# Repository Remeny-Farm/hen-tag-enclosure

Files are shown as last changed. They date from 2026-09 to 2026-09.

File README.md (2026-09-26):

> **Moved (2026-09-26).** This repository is archived. The enclosure now lives, with its full history, in the Open Source Farming catalogue:
> https://github.com/Remeny-Farm/open-source-farming-catalog/tree/main/projects/holyiot-25008-enclosure
> Contributions, issues and build reports go there. The site entry is https://opensource.mootopia.wtf/#holyiot-25008-enclosure (English) and https://opensource.remeny.farm/#holyiot-25008-enclosure (Hungarian).

# Hen Tag Enclosure

Parametric, 3D-printed enclosure for the Remeny Farm hen tag: a small
BLE activity tag worn by free-range laying hens under the farm's hen-patron
program. This repository holds the mechanical design only — the parametric
[build123d](https://build123d.readthedocs.io/) CAD source, the verification
and per-tag cap generators, and the physical evidence gathered from printing
and fitting it — as real solid-body CAD (STEP as well as STL), not a dead
triangle mesh.

## Hardware context

The tag is built around a **Holyiot 25008** module (Nordic **nRF54L15** SoC,
ST **LIS2DH12** accelerometer) powered by a **CR2032** coin cell. It is worn
by the hen on a figure-eight elastic harness through the enclosure's in-plane
side tabs, assembled and installed by farm staff following the documented
procedure. The electronics and firmware live in a separate, private
repository; this repository covers the mechanical enclosure only.

The design is welfare-first: the current (Revision B) model lands at
**10.92 g assembled**, conductive/carbon-fibre filament is strictly
prohibited (it detunes the 2.4 GHz antenna and creates an ESD/short hazard
against the exposed coin-cell terminals), and every geometry decision is
checked against interference, wall thickness and printability before it is
considered done. See [`docs/requirements.md`](docs/requirements.md) for the
full material and welfare-adjacent requirements this design has to satisfy.

## Goals

- **Durable, hen-safe enclosure** — a sealed transparent PETG housing (radial
  O-ring, target IP54-level dust/splash protection — not yet tested), no
  conductive filament, and a mass budget held close to a 10 g target.
- **Per-hen customizable cap** — [`cad/cap_marking.py`](cad/cap_marking.py)
  generates a deterministic, per-hen cap (id number, an optional short
  message, an icon) and exports it straight to a ready-to-slice, multi-colour
  Bambu Studio project.
- **Accessory platform** — [`platform/`](platform/) proposes a keeper collar
  and bayonet mount so decorative and functional accessories can be added
  without ever modifying or replacing the shipping cap. Proposal stage, open
  for contribution.
- **Community contributions** — parametric, machine-verified, test-covered
  source with dated physical lab notes and explicit verified-vs-unverified
  labeling, so outside contributors have a real basis to trust and extend the
  design. See [`CONTRIBUTING.md`](CONTRIBUTING.md).

## Per-hen cap customisation

Patrons choose a colour scheme, an icon or a centre pattern and a top-band
pattern for their hen's cap in the app and lock the design; staff batch one
scheme's locked caps onto one printer plate. Design and requirements:
[`docs/superpowers/specs/2026-09-14-hen-cap-customisation-design.md`](docs/superpowers/specs/2026-09-14-hen-cap-customisation-design.md).

```sh
cd cad
uv run --python 3.12 cap_marking.py 67 --icon sun --band dots     # one cap with a band pattern
uv run --python 3.12 cap_batch.py fixtures/batch_sample.json       # batch JSON -> plate + manifest + proofs
cd ../editor && pnpm install && pnpm dev                            # the patron editor prototype
```

- [`cad/catalog.json`](cad/catalog.json) is the source of truth for the
  colour schemes (base + two free colours, Prusament Clear window; five on
  offer since 2026-09-18, three retired ones kept printable for designs
  already locked on them), the packs (basic free, vibe 50, drop 300–1000
  limited, priced per item), 34 icons, 16 patterns, the five colour zones
  (a translucent filament may not go on the opaque ring or number) and the
  fees; the app ships an identical copy.
  [`cad/cap_motifs.py`](cad/cap_motifs.py) holds every motif as parametric
  geometry, [`cad/check_motifs.py`](cad/check_motifs.py) proves them printable.
- [`cad/cap_batch.py`](cad/cap_batch.py) turns the admin's batch JSON into
  `plate_<batch>_P1S.3mf` (6 × 6, up to 36 caps, AMS 1 clear / 2 text /
  3 accent, print settings baked in), a manifest and a proof SVG per cap.
  A 36-cap plate slices to 36 objects in an estimated 4 h 13 m
  ([lab note](docs/lab/2026-09-14-cap-batch-plate.md)); **no plate has been
  printed yet.**
- [`editor/`](editor/) is the drop-in patron editor built with chirp's own
  UI package; see its README for how it maps into the chirp repository.

## Repository structure

| Path | Contents |
|---|---|
| [`DESIGN.md`](DESIGN.md) | Full mechanical design spec: decisions, verification results, print settings, open questions. |
| [`docs/requirements.md`](docs/requirements.md) | Source-of-truth requirements: materials, sealing/ingress target, conformal-coating protocol, form factor. |
| [`docs/lab/`](docs/lab/) | Dated lab notes: physical measurements, print trials, photo-based findings. |
| [`cad/`](cad/) | Parametric build123d source, the per-tag cap generator, the batch CLI and plate writer, the verification scripts, and the test suites. |
| [`editor/`](editor/) | Patron cap-editor prototype (React, chirp UI package), browser-testable, drop-in for chirp. |
| [`cad/out/`](cad/out/) | Exported STL/STEP. Stable printables (body, cap, fit coupons) are committed; per-tag and debugging outputs are gitignored — see `cad/out/.gitignore`. |
| [`platform/`](platform/) | Accessory-platform **proposal**: keeper collar, bayonet interface spec, saddle integration. Not yet built. |
| [`CONTRIBUTING.md`](CONTRIBUTING.md) | How to contribute: environment, verification requirements, lab-note style, accessory safety envelope. |
| [`LICENSE`](LICENSE) | MIT license. |

## Quickstart

Both CAD scripts carry [PEP 723](https://peps.python.org/pep-0723/) inline
dependencies, so `uv` resolves everything (build123d, bd_warehouse) on first
run. No virtualenv, nothing installed into the repository.

```sh
cd cad

# Build the enclosure and export STEP + STL to out/
uv run --python 3.12 hen_tag_enclosure.py

# 39 machine checks (interference, fit, bayonet, wall thickness, seal, harness) + half sections
uv run --python 3.12 verify.py

# Generate one hen's cap: id, optional message, icon
uv run --python 3.12 cap_marking.py 67 --top "Bözsi!" --icon heart

# Generator test suite (add --bambu for the full Bambu Studio export path)
uv run --python 3.12 test_cap_marking.py

# Real-slicer check: warnings + travels over open air (needs Bambu Studio)
uv run --python 3.12 slice_check.py

# Bambu Studio project with all four parts and the print settings baked in
uv run --python 3.12 slice_check.py --project   # -> out/hen_tag_revC_P1S.3mf
```

First run downloads the OCCT wheel (~60 MB) and a CPython 3.12 toolchain;
after that it is cached. `verify.py` exits non-zero on any failed check, so
it works as a pre-commit or CI gate. See [`cad/README.md`](cad/README.md)
for the full command reference, including re-checking a part against the
real slicer.

## Print settings

| Setting | Value | Why |
|---|---|---|
| Material | Transparent PETG | Impact resistance, UV stability, low moisture absorption; keeps the LED and lettering readable. |
| Nozzle | 0.40 mm | Thinnest wall in the design is 0.80 mm = 2 perimeters. |
| Layer height | 0.16 mm | The bayonet ramps and the O-ring groove need the resolution. |
| Perimeters | 3 | The bayonet lips make the skirt 5 lines thick in places. |
| Wall generator | **Arachne** | Variable-width walls absorb the lips as walls, not infill islands. |
| Avoid crossing walls | **On** | Routes travels over the print, not across the open bore; without it PETG strings the bore (58 → 3 crossing travels on the cap coupon). |
| Infill | 30 %+ | Parts are nearly all perimeter anyway. |
| Supports | None | Verified by slicing — all four parts return `Success.` with zero warnings. |
| Orientation | Already baked into the exported STLs | Drop them on the plate as-is; re-orienting the cap turns its top plate into a ~28 mm bridge. |

Or skip the settings altogether: [`cad/out/hen_tag_revC_P1S.3mf`](cad/out/hen_tag_revC_P1S.3mf)
is a Bambu Studio project with the four printables on one P1S plate and every
setting above already applied — open, slice, print.

Full rationale, tolerances and the slicer verification log are in
[`DESIGN.md`](DESIGN.md#print-settings).

## Design highlights

- **Radial seal, not an axial face seal** — the O-ring seals on a bore
  diameter instead of a compressed flange, which also removes ~1.7 g of pure
  overhead. [`DESIGN.md`](DESIGN.md#1-radial-seal-not-the-axial-face-seal)
- **Bayonet closure below the seal** — three lugs and self-locking helical
  ramps replace a thread whose ridges were thinner than one extrusion; every
  face on both parts prints without support, and the O-ring never crosses the
  lugs. [`DESIGN.md`](DESIGN.md#9-bayonet-not-a-thread)
- **Three-colour coin cap** — a deterministic per-hen cap with coin-style
  bent lettering, an accent-ring icon, and a clear shell so the LED needs no
  aligned window. [`DESIGN.md`](DESIGN.md#8-customer-cap-clear-shell-big-coin-lettering-accent-core)
- **Flat underside** — verified at 0.000 mm³ of material below the floor
  plane, so nothing presses on the hen but the harness itself.
  [`DESIGN.md`](DESIGN.md#7-in-plane-side-tabs-for-the-harness)
- **In-plane side tabs** — the harness elastic wraps a bar on two flat tabs
  in the plane of the base, which is what makes the flat underside possible.
  [`DESIGN.md`](DESIGN.md#7-in-plane-side-tabs-for-the-harness)

## Status

**v1 is Revision C geometry.** It is machine-verified — 39 checks in
`cad/verify.py`, all passing — but that is a claim about the model, not about
a worn device:

- **Revision A** was printed and fitted on a Bambu Lab P1S: dimensions good,
  and its thread mated on that one pair. Later caps tore along the thread,
  whose ridges compute to less than one extrusion wide, so revision C
  replaced it with a bayonet.
- **Revision B's body** has also been printed and accepted the board in its
  intended orientation, and revision B sliced clean in Bambu Studio.
- **Revision C's bayonet** slices clean and its coupon pair has been printed
  once: dimensions good, lock-up angle not yet reported. The full cap, the
  complete sealed assembly and the harness tabs under load remain untested —
  no O-ring has been compressed, no water has touched it, and no elastic has
  loaded a tab.
- **No hen has worn this device.**

See [`DESIGN.md`](DESIGN.md#verified-evidence-vs-working-hypotheses) for the
full verified-vs-unverified breakdown and the open questions blocking the
next print.

## Animal welfare

The tag is worn continuously by a live animal, so mass and fit are treated as
hard constraints, not just engineering targets. At ~10.9 g assembled the
device is a small fraction of a laying hen's typical body mass — well inside
commonly cited bio-logging guidance of keeping an attached device under
roughly 3 % of body mass — though `DESIGN.md` is explicit that whether the
project's own 10 g figure is a hard welfare limit or a design aspiration is
still an open decision, not yet resolved. The design avoids magnets, sharp
edges and anything a beak could catch or detach; production tags are
assembled and fitted by farm staff, with daily visual checks as part of
normal husbandry. This is not a consumer product for end users to assemble
or fit themselves.

## Accessory platform

[`platform/`](platform/) is a **design proposal**, not a shipping feature:
nothing in it has been printed or tested, and the current shipping design
(`DESIGN.md`, `cad/hen_tag_enclosure.py`) is untouched by it. It describes a
keeper collar and quarter-turn bayonet mount for a family of accessories —
decorative rings, villa-only builds, a mesh saddle — without ever modifying
the personalised cap. It is open for contribution; see
[`platform/README.md`](platform/README.md) for the architecture and
[`platform/accessories.md`](platform/accessories.md) for the hard safety
envelope every accessory design must satisfy.

## Contributing

See [`CONTRIBUTING.md`](CONTRIBUTING.md) for the development environment,
what has to pass before a PR (generators, `verify.py`, the test suite), how
physical evidence is recorded, and the accessory safety envelope.

## License

MIT. See [`LICENSE`](LICENSE).

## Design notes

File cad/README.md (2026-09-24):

# Enclosure CAD

Parametric source for the hen tag enclosure. Solid B-rep modelling via
[build123d](https://build123d.readthedocs.io/) on the OCCT kernel, so the output
is real CAD geometry with true fillets and helical sweeps, exported as **STEP as well
as STL** — the model stays editable in FreeCAD or any other CAD tool rather than
being a dead triangle mesh.

## Running

Both scripts carry PEP 723 inline dependencies, so `uv` resolves everything on
first run. No virtualenv, and nothing is installed into the repository.

```sh
uv run --python 3.12 hen_tag_enclosure.py   # build + export to out/
uv run --python 3.12 verify.py              # 39 machine checks + half sections (+9 with --board-step)
uv run --python 3.12 slice_check.py         # real-slicer check, needs Bambu Studio
```

First run downloads the OCCT wheel (~60 MB) and a CPython 3.12 toolchain; after
that it is cached. `verify.py` exits non-zero when a check fails, so it works as
a pre-commit or CI gate.

**STLs are exported already lying in their print orientation** — the cap and the
female coupon are flipped top-plate-down on export. Drop them on the plate as
they are; re-orienting the cap makes its top plate a ~28 mm bridge. The STEP
files keep the design coordinate system so the model stays readable in CAD.

`slice_check.py` re-checks printability against the real slicer: it runs the
Bambu Studio CLI on the four printables with the P1S 0.4 mm machine, the
0.16 mm process, PETG Basic, and the three settings `../DESIGN.md` asks for
(3 walls, Arachne, avoid crossing walls), then reads the G-code back and
counts travel moves that fly across open air — the bore of the cap, the cavity
and cell pocket of the body — where PETG leaves a string. It fails on a slicer
warning or when a count exceeds a limit set just above the 2026-09-10 numbers.
`--stock` slices with the untouched Bambu profile for comparison, `--keep`
leaves the G-code in `out/slice/`. Skips with exit 0 when Bambu Studio is not
installed.

## Per-tag cap markings — the deterministic tag generator

```sh
uv run --python 3.12 cap_marking.py 67 --top "Bözsi!" --icon heart
uv run --python 3.12 cap_marking.py 12345 --icon star
uv run --python 3.12 cap_marking.py 133 --icon flower --font tahoma
uv run --python 3.12 test_cap_marking.py            # test suite; --bambu for the full path
```

This is the back end for the customer design UI. The inputs are exactly the
customer-facing choices, everything else is fixed:

| Input | Envelope |
|---|---|
| number | **required**, 1–5 digits, bottom arc, 6.0 pt |
| `--top` message | ALL CAPS coin lettering at 5.2 pt; letters incl. Hungarian (ő/ű), digits, space, `.:!?'"+-`; **guaranteed-safe length: 8 characters** (all-'W' worst case), typical texts fit ~11–13 — over-length is rejected with the measured span |
| `--icon` | `heart` / `star` / `flower` / `none` — parametric shapes in the centre |
| `--font` | curated list: verdana (default), tahoma, arial, futura, din, rounded |

**Layout (second print-driven revision): the whole shell is CLEAR PETG.** The
first trial printed the lettering at a 2.9 mm band and it was unreadable, and
the product look wanted a transparent body anyway. With the shell clear, the
dedicated LED window disappears — the LED shines through wherever it lands, so
there is nothing to align — and the lettering band grows to ~6 mm: double the
letter height, at the price of a shorter message. The centre is a full
**accent disc** (Ø17.2) in the third colour with the icon cut out of it and
inlaid in the text colour — the two colours meet edge to edge, no clear gap.

| Slot | Body | Filament |
|---|---|---|
| 1 | `cap_<n>` | the whole shell — **clear PETG** |
| 2 | `marking_<n>` | lettering + icon, text colour (0.64 mm flush inlay) |
| 3 | `core_<n>` | accent disc, the icon cut from it (0.64 mm flush inlay) |

Deterministic by design: **font sizes are fixed**, misfits are rejected with
measured numbers, and identical input produces **byte-identical** output
(canonically ordered welded meshes, deterministic STL writer, fixed zip
timestamps) — a regenerated tag can be diffed against a shipped one.

Envelope rules the test suite forced: the message is uppercased (a lowercase
descender plus an accented capital outgrows any printable band height, while
accented capitals alone fit), and comma/semicolon/parentheses are excluded
from the charset for the same below-the-baseline reason.

The deliverable for the P1S is **`out/cap_<n>_P1S.3mf`** — a Bambu Studio
project with the three bodies as parts of ONE object (`--assemble` via the
Bambu CLI, so nothing can be arranged apart or dragged out of register) and
the filament slots pre-assigned. Open it, load the project settings, put clear
PETG in AMS slot 1, the text colour in 2, the accent colour in 3, slice. Each
part's `extruder` is patched into `Metadata/model_settings.config`, the
assembler's per-part recentring is undone with measured translations, and the
result is verified numerically against the source solids plus round-tripped
through the CLI. Needs `/Applications/BambuStudio.app`; without it only the
vendor-neutral `cap_<n>.3mf` + per-part STLs are written (assign filaments by
hand in other slicers).

Because the cap prints top-plate-down, all three bodies meet in the first
layers against the plate; the outer face comes out as one smooth plane. There
is no clear layer over or under the inlays — the first layer is already the
final colour. A washed-out colour means the coloured PETG itself is
translucent at 0.64 mm: deepen with `--depth` (up to 0.80) at the cost of
thinner cover above.

The 3MF is written by the script itself: one mesh object per body (libraries
explode the glyphs into a dozen objects), tessellation **welded** (OCCT
duplicates vertices per face; 3MF importers trust the index buffer and the
cracks sliced into "floating region" warnings) and refused if any non-manifold
edge remains. Lettering defaults to **Verdana** with the full Hungarian glyph
set; hairline strokes are lifted by dilation and any printable feature under
0.58 mm is refused. Icons are parametric geometry, no emoji fonts. The cap's
closure, seal and envelope are untouched — `build_cap()` is imported, not
copied.

## Files

| File | Role |
|---|---|
| `hen_tag_enclosure.py` | All geometry. `Params` at the top holds every dimension. |
| `catalog.json` | Schemes, icons, centre/band patterns and fees a patron may choose; the app ships a copy, `test_cap_marking.py` keeps them identical. |
| `cap_design.py` | Catalog loader, `design_hash` (v2, with zone colours), `validate_design` (zone rules incl. no translucent filament on an opaque zone; retired schemes stay valid), `lock_price`; no build123d, shared by the batch CLI and the tests. |
| `cap_motifs.py` | Every icon and pattern as a parametric sketch (34 icons, 3 centre, 13 band patterns; the barcode band is seeded by the serial). |
| `check_motifs.py` | Printability of the whole motif library (erosion/dilation, extents) plus a contact sheet (`--svg`). |
| `cap_svg.py` | Sketch → SVG: `out/layout.json` for the app preview, proof SVGs for the batch. |
| `bambu_project.py` | Pure-Python Bambu Studio plate writer (6 × 6 grid, part extruders, settings template in `bambu/`). |
| `cap_batch.py` | Batch JSON → plate, manifest, proofs; caches bodies per design hash; runs `slice_check.py` on the plate. |
| `test_bambu_project.py`, `test_cap_batch.py` | Writer and batch suites (structure, determinism, refusals, a real slice). |
| `verify.py` | Interference, fit, bayonet, wall thickness, seal and harness checks. |
| `slice_check.py` | Real-slicer check: warnings and open-air travel counts per part; `--project` writes the ready-to-print Bambu project. Needs Bambu Studio. |
| `out/hen_tag_revC_P1S.3mf` | Bambu Studio project: body, cap and both coupons on one P1S plate, print settings baked in. |
| `cap_marking.py` | Deterministic per-tag cap generator (number, message, icon, font). |
| `test_cap_marking.py` | Generator test suite: envelope, rejections, determinism. |
| `out/body.stl` / `.step` | Main housing. |
| `out/cap.stl` / `.step` | Bayonet cap. |
| `out/coupon_*.stl` | Bayonet + groove fit coupons. Print these first: the bayonet has not been printed anywhere yet. |
| `out/section_*.stl` | Half sections, for looking at the internals only. |

## Changing dimensions

Every dimension lives in the `Params` dataclass. Derived values — groove depth,
lug and lip stations, cap diameter, Z stations — are computed properties, so changing
one input propagates correctly instead of leaving stale constants behind.

The values most likely to need correcting, all currently UNVERIFIED:

```python
holder_h   = 4.0    # holder + seated cell, off the PCB face (board itself: STEP)
oring_cs   = 1.50   # measure the ring you actually have
strap_w    = 8.80   # slot length; measure the elastic you actually have
strap_t    = 1.80   # slot width, along the spine
foam_t     = 2.0    # foam ring over a 1.79 mm gap to the board face
```

Board orientation is **holder down, PCB up** — the LED has to look out through
the cap, not at the bird. `cell_fill()` builds the crescent that retains the
holder; `strap_tabs()` builds the in-plane side tabs; `body_lugs()` and
`cap_channels()` build the two halves of the bayonet, both from one helical
sweep helper so their bearing faces share a pitch.

### Batch workflow

1. The app's admin page downloads a `hen-cap-batch/1` JSON: one scheme, up to
   36 locked caps (serial, icon *or* centre pattern, band pattern, design
   hash, hen name). `fixtures/batch_sample.json` is the shape.
2. `uv run --python 3.12 cap_batch.py <batch.json>` refuses the whole batch on
   any problem (schema, `generator_version` ≠ `catalog.json`, unknown ids,
   icon + centre together, a zone colour rule, a translucent filament on the
   ring or number, duplicate serial, bad hash, > 36 caps; a retired scheme is
   accepted) and lists
   every offending cap; otherwise it writes `out/plates/plate_<id>_P1S.3mf`,
   `plate_<id>_manifest.csv` (`position,serial,hen_name,design_hash`,
   positions `1A`…`6F`) and `proof/<design_hash>.svg`, then slices the plate
   through Bambu Studio and reports objects, warnings and the time estimate.
3. Open the plate in Bambu Studio, set AMS 1 = the scheme's base filament,
   2 = Prusament PETG Clear, 3 = colour a, 4 = colour b (`catalog.json` names
   them; the batch CLI prints the mapping), print. The plate carries the
   `Bambu PETG Basic @BBL X1C` preset in all four slots whatever the scheme
   (Prusament, Bambu PETG Basic, or Bambu PETG Translucent in `lavender`'s
   slot 4): the per-filament arrays stay as exported (see
   `bambu_project.py`): temperatures and flow come from that preset, the
   AMS mapping on the printer decides which spool feeds each slot. Whether
   PETG Translucent prints well on the Basic preset is UNVERIFIED.
4. Upload the proofs to the app (file name = design hash).

Patterns must survive a 0.4 mm erosion (feature ≥ 0.8 mm) and a 0.4 mm
dilation without islands merging (gap ≥ 0.8 mm), and every inlay together must
leave ≥ 60 % of the LED ring (r 8.5–11.5) clear; `cap_marking.py` checks all
three. Band patterns live in a fixed window (−10°…190°) that clears a 5-digit
serial by 22°.

After any change, re-run `verify.py` before printing. It is what caught the
assembly-path defect described in `../DESIGN.md`.

## Bayonet fit

Print the coupons and note where the cap stops turning freely. Nominal is 30°
clockwise from the entry slots; anywhere from about 5° to 55° still locks. Then
adjust and regenerate — do not file the parts:

```python
cam_lock   = 30.0   # deg of rotation to nominal contact: raise if it locks early, lower if late
fit_lug_r  = 0.15   # radial clearance, lug crest to channel root: raise if the lugs bind
fit_lug_z  = 0.30   # axial clearance, lug top to channel ceiling
cam_rate   = 0.012  # ramp rise per degree; lower for a longer, softer tightening
```

Note for anyone extending this: the cap is modelled in its **locked** pose, so
the cap solid is already the assembled one. `verify.py` turns it back toward
the entry angle (`pose(phi)`) to prove the drop-on, the free run and the wedge.
Lugs and lips are swept along helices of the same pitch; change `cam_rate` and
both follow.

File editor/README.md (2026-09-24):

# Hen cap editor — prototype

Browser-testable prototype of the patron-facing cap editor from
`../docs/superpowers/specs/2026-09-14-hen-cap-customisation-design.md` §7.
It is written to be dropped into the chirp repository unchanged, so it renders
with chirp's own `@chirpcoop/real-chicken-ui` components and
`@chirpcoop/design-tokens`, aliased **from the chirp checkout's source** — the
chirp repository is read, never written.

```sh
pnpm install
pnpm sync:data     # copies ../cad/catalog.json and ../cad/out/layout.json into src/cap-editor/data/
pnpm dev           # http://localhost:5173 with the in-memory mock client
pnpm test          # vitest + testing-library
pnpm typecheck
pnpm build
```

`CHIRP_DIR` overrides the chirp checkout location (default `../../chirp`);
`tsconfig.json`'s `paths` must be edited to match, tsc cannot read env.

## What it looks like

A three-step game — Palette → Motif → Colours — with the cap on stage and a
summary bar stuck to the bottom. Design decisions, the mobile integration
path and a reviewer checklist: [`DESIGN-NOTES.md`](DESIGN-NOTES.md).

## Rules the code already obeys

- Only `var(--rc-*)` and `@chirpcoop/design-tokens` values in TS/CSS; the
  only colour literals are the filament hexes in `data/catalog.json` (data).
- Deep imports only: `@chirpcoop/real-chicken-ui/components`, `/wallet-pill`,
  `/golden-grain`, `/theme-vars`, `/dialog-focus`, `/armed-confirm`,
  `/styles.css`. Never `/client` or `/index`: they pull `@chirpcoop/client-sdk`
  and recharts in. In chirp these become relative imports inside the package.
- React 19, TypeScript strict, vitest + testing-library, English-only source;
  Hungarian only inside `src/copy/hu.ts`.

## Integration map (landed in chirp on 2026-09-14, PR Remeny-Farm/chirp#2409; kept for orientation)

| Prototype file | Lands in chirp as |
|---|---|
| `src/cap-editor/*.tsx`, `*.css`, `*.test.tsx` | `packages/real-chicken-ui/src/cap-editor/` |
| `src/copy/{hu,en}.ts` | keys in `apps/web/i18n/` catalogs |
| `src/cap-editor/types.ts` (`CapDesignClient`) + `mock-client.ts` | interface stays; SDK adapter in `apps/web/lib/`; mock stays for tests |
| `src/page.tsx` | `apps/web/app/(patron)/my-hen/cap/page.tsx` + client wrapper |
| `src/cap-editor/data/*.json` | data assets under `packages/real-chicken-ui/src/cap-editor/data/` |

## Layout gate (manual, needs Playwright)

`pnpm test` runs in jsdom and cannot see geometry. `pnpm check:layout` drives a
real Chromium against a running dev server and fails on page-level horizontal
overflow on any step at 360 / 390 / 1200 px, on a rail that does not scroll
sideways on its own, on an arrow-focused tile left cut off at the rail edge,
and on any chip / tile / tab / card under 44 px. Playwright is not a
devDependency (browser download), so point `NODE_PATH` at an install that has
it:

```sh
pnpm dev                                          # terminal 1
NODE_PATH=/path/to/node_modules pnpm check:layout  # terminal 2
```

Run it before every UI change lands; the scoring reviewer checks the same
things.

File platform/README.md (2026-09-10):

# Accessory Platform — Design Proposal (separate from the shipping design)

## Purpose & Status

Design for making the existing Rev B tag the mounting platform for a family of
accessories (decorative add-ons, villa builds, saddle integration) **without
changing anything the current tag already does**: LED ring window, coin
lettering, radial seal, bayonet cap, flat underside, harness tabs, mass budget.

- **Status: PROPOSAL. Nothing here has been printed or tested.**
- These files are deliberately separate. `../DESIGN.md` and
  `../cad/hen_tag_enclosure.py` are untouched; the current design remains the
  shipping design and works with or without the platform parts.
- Direction and welfare constraints follow a three-tier model: T1 always-worn
  accessories in the flock, T2 "villa wardrobe" builds only in the wellness
  villa, T3 functional mesh saddle. Active feather pecking exists in the
  flock; summer peaks hit 42 °C.

## Files

| File | Contents |
|---|---|
| [`collar.md`](collar.md) | The keeper collar: the one new load-bearing part. Clamshell ring that locks the cap and carries the bayonet mount. |
| [`accessories.md`](accessories.md) | Bayonet interface spec v0.1, hard safety envelope, T1 catalog (halo ring, flush medallion, low dome), T2 villa rules. |
| [`saddle-integration.md`](saddle-integration.md) | Mesh saddle with grommet window and the fabric-lock ring that registers it to the tag. |

## Architecture in one paragraph

A two-piece **keeper collar** clips around the cap skirt. It is keyed by the two
harness tabs (so it cannot rotate), rests on the tab shoulders, and hooks over
the cap rim with a lip that stops **outside** the lettering band — every printed
feature of the cap face stays visible. Clamping the skirt (plus ribs matching
the existing grip scallops) locks the cap against turning open. The collar's crown
carries a **quarter-turn bayonet** ring: accessories twist on and off with a
motion a beak cannot reproduce, and any torque they receive is routed
collar → tabs → body, never into the cap closure. With no accessory mounted the
tag looks almost exactly as it does today, plus a slim ring around the skirt.

## What must change on the current tag

**The cap: nothing, ever.** The personalised transparent cap (lettering, LED
window) is never modified and never replaced — this is a hard user
requirement. A first iteration put the collar's retention groove on the cap
OD; **rejected 2026-08-30** because it would have meant reprinting
personalised caps.

**The body gets one cut** — the `body_platform` variant
(`../cad/hen_tag_platform.py`, built and machine-checked, not yet printed):
a lateral retention groove on the base-flange OD (z −0.55…0.00, 0.5 deep,
root r 15.47). The collar's bottom bead enters it sideways as the clamshell
closes: positive up/down lock with zero flexing, and every accessory load
routes collar → body → harness, **bypassing the cap closure entirely** — which
also dissolves the original cap-opening concern. The body is the generic
part: existing tags swap to a grooved body at a normal battery service and
the personal cap carries over unchanged; until then the collar fits existing
bodies in friction-only mode (bench work yes, deployment no).

Machine-verified on 2026-08-30: the variant removes 30.1 mm³, adds 0.0 mm³ —
closure, seal band, cavity, tabs, flat underside untouched; the collar coupon
shows 0.000 mm³ interference against both the grooved body and the cap, and
its lowest point stays 0.40 mm above the floor plane (it never touches the
hen). Optional Rev C nicety: 0.3 mm pad-seat recesses on the tab shoulder
ledges.

## Frozen interface (contract for every future revision)

Any revision that keeps these values stays collar-compatible. Values from
`hen_tag_enclosure.py` (Rev B, unchanged by the Rev C bayonet closure):

| Parameter | Value | Why frozen |
|---|---|---|
| Cap skirt OD (`2*r_cap_out`) | 31.94 mm | collar bore, lip radius |
| Cap face height (assembled) | 8.70 mm | collar crown deck height |
| Rim edge zone | r 15.4–15.97 | lip lands here, outside lettering |
| Lettering band | r 12.5–15.4 | must stay uncovered |
| Clear LED ring | r 8.5–11.5 | optical keep-out for accessories |
| Grip scallops | 8 × 45°, R1.4 cutter, 0.25 deep | anti-rotation ribs mate these |
| Tab width (`tab_w`) | 13.00 mm | rotation key windows |
| Tab shoulder height | z = +2.20 (tab_top) | collar support pads land here |
| Slot span (`r_slot_in`–`r_slot_out`) | r 16.77–18.57 | elastic must stay clear |
| Tab span (`2*r_tab_out`) | 40.14 mm | saddle grommet sizing |
| Flat underside | 0 mm³ below floor plane | collar must also respect it |

## Safety inheritance

The welfare framework below gates everything here. Hard rules
repeated where they bite: no magnets; no part a peck can detach (bayonet +
detent, tool-release clamshell); no dangling elements; ≤5–10 g per accessory,
worn total target 25–30 g; muted matte colours in the flock (active pecking);
bright/tall builds only in the villa; bleach-only disinfection of PETG
(alcohol degrades FDM parts); collar and accessories are cheap consumables —
replace rather than scrub when soiled.

## Verification plan (before any hen wears any of this)

1. Print the collar fit coupon (defined in `collar.md`), then a full collar.
2. **Torque test**: measure the cap's break-loose torque; with collar fitted,
   apply 3× that torque to a mounted dummy accessory — cap must not move.
3. **Pull-off**: mounted accessory must survive ≥30 N axial pull
   (≈2× a hen's grab-peck force, 15 N literature value).
4. **Cycling**: 50 mount/dismount cycles, re-check detent and clamp.
5. **Elastic check**: thread the 8 mm elastic with collar fitted — zero
   interference through the slot windows.
6. Mass on the scale: collar ≤2.5 g target.
7. **RF A/B**: RSSI with and without collar (antenna location is unknown).
8. **Chemistry**: 24 h in 3 % bleach solution, re-test snap and detent.
9. Only then: on-hen habituation trial per the welfare protocol
   (2–7 days close watch), daily checks unchanged.

## Open questions

- Actual cap break-loose torque (bench, needed for the 3× margin).
- Whether friction-only cap lock suffices on unmodified Rev B caps, or the
  Rev C finer scallops are required for the positive lock.
- Antenna keep-out: no data; the RF A/B test answers whether the collar wall
  (PETG, ≥2 mm off the body wall) matters at all.
- Vet sign-off items and certifier notification per the welfare framework.

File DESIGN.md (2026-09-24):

# Hen Tag Enclosure — Design Specification

## Purpose & Status

Parametric two-part enclosure for the Holyiot 25008 tag, generated from code in
`cad/hen_tag_enclosure.py`.

- **Status**: Revision C. Geometry generated, machine-verified, exported.
  **Revision C's coupon pair has been printed once (dimensions good); the
  lock-up angle is unreported and the full cap unprinted.**
- **Revision A was printed and fitted** on a Bambu Lab P1S — dimensions good,
  and its thread mated on that one pair. See
  `docs/lab/2026-08-28-enclosure-print-trial.md`. Later caps tore along the
  thread, whose ridges compute to less than one extrusion wide; the thread
  was replaced by a bayonet on 2026-09-10. See
  `docs/lab/2026-09-10-thread-print-failure.md` and decision 9. The board
  dimensions still are not empirical.
- **Blocking caveat**: the board dimensions this design is built on are operator
  caliper readings that carry an unresolved ambiguity. See
  `docs/lab/2026-08-28-enclosure-board-measurements.md`.

---

## Summary

| | |
|---|---|
| Assembled envelope | **40.14 × 31.94 × 8.70 mm** (Ø31.94 body, tabs to 40.14) |
| Printed mass (PETG) | **5.01 g** (body 2.71 + cap 2.30) |
| Assembled mass | **9.92 g** — within the 10 g target (board mass from the manufacturer STEP; cell, holder and ring still estimates) |
| Orientation | Holder **down** toward the harness, PCB **up**, LED outward |
| Sealing | Radial NBR O-ring, **ID 26.74 × CS 1.50 mm** |
| Closure | Bayonet: 3 lugs × 20°, 0.80 mm proud, 30° clockwise onto self-locking helical ramps |
| Material | Transparent PETG. Conductive/CF filament remains prohibited. |

```
                              Ø31.94
              ┌──────────────────────────────┐   cap top 1.10
              │ ▁▁▁  Ø16 LED window  ▁▁▁     │   foam recess 0.30
         ═════╪══════════════════════════════╪═════  ceiling z=6.60
              │      ░░░   S1   ░░░          │   foam RING OD16/ID12 x 2.0
              │ ▓▓▓▓▓ PCB Ø25 ▓▓▓▓▓ z=4.81/6.41│   ← LED faces the cap
         ○────┤ ▓▓▓▓▓▓▓▓▓▓▓▓▓▓▓▓▓▓▓▓▓▓ z=4.0 ├────○  O-ring, z=3.71…5.74
              │███┌──────────────────┐███████│   seals on band r=13.70
              │███│ CR2032 + holder  │███████│   ███ = fill, holds the holder
    ▓▓▓▓▓▓▓▓▓▓╪███│ Ø21, offset 2.0  │███████╪▓▓▓▓▓▓▓▓  3 lugs z=1.80…3.10
    ┌─────┐   │▁▁▁└──────────────────┘▁▁▁▁▁▁▁│   ┌─────┐  floor 1.00
    │  ▄  │═══╡        cell rests on the floor  ╞═══│  ▄  │  ← in-plane tabs
    └─────┘   └──────────────────────────────┘   └─────┘     slot 8.8 x 1.8
                    FLAT UNDERSIDE                           bar 1.5
```

---

## Design Decisions

### 1. Radial seal, not the axial face seal

`docs/requirements.md` originally specified an axial face seal on an NBR 30 × 2 mm ring.
A face seal must sit **outboard of the cap skirt**, which forces a flange out to
Ø36 around a Ø25 board. Modelled and weighed, the three options were:

| Variant | OD | Plastic | Assembled |
|---|---|---|---|
| Face seal, NBR 30×2 (original spec) | 36.0 mm | 6.01 g | 11.88 g |
| Face seal, NBR 24×2 | 31.1 mm | 4.40 g | 10.26 g |
| **Radial seal (adopted)** | **31.9 mm** | **4.32 g** | **10.19 g** |

The flange was ~1.7 g of pure overhead. The radial seal needs none.

> Those masses compare the three sealing strategies on identical revision A
> bodies. Revision B is heavier (5.05 g) because of the cell fill and the tabs;
> the comparison between strategies is unaffected.

Second advantage, specific to FDM: a radial seal's compression is set by the bore
diameter, not by how hard the cap is tightened. The face seal needed a stop
flange precisely to stop the operator from shearing the ring — a failure mode the
radial arrangement does not have.

### 2. Closure low, seal high

The first layout put the seal below the thread and **could not be assembled**.
The cap's internal thread crests sat at r 14.00; sliding them down past a
sealing band at r 14.30 is a collision. Caught by `verify.py`, not by eye.

Inverting it fixes the assembly path and adds a second benefit: **the O-ring
never travels across the closure**, which would shred it. The rule survived
the change from thread to bayonet (decision 9) unchanged: the lugs sit at
z 1.80–3.10, the groove starts at z 3.91, and the checks that enforce it are
`cap bore clears the seal band` and `O-ring never crosses the lugs` in
`verify.py`.

### 3. Holder down, PCB up

The LED sits on the PCB face. With the board the other way up it pointed at the
bird and was unreadable. Inverted, the PCB looks into the transparent cap and
the LED can be read on a closed tag.

This also removes an old awkwardness. Because the holder is internally tangent
to the PCB, **no rotationally symmetric ring lands on bare PCB all the way
round** when the holder faces up — at the tangent point the holder reaches the
board edge exactly. With the holder underneath, the PCB presents a full Ø25 disc
to the cap, so a plain annular clamp works.

### 4. Fill around the cell

The crescent of cavity the offset holder does not occupy is filled solid from
the floor to just under the PCB face. That fill is what holds the holder: 100 %
of the holder's circumference is backed either by fill or, at the tangent point,
by the cavity wall itself.

The fill deliberately stops 0.20 mm **short** of the PCB rather than seating it.
The board still rests on its own holder, and the fill never touches whatever
components sit on that face (the STEP's generic clip model does not show them
reliably). It costs about 0.7 g.

### 5. Tolerance lives in a foam ring, not a pad

A 2.0 mm closed-cell foam **ring**, OD 16 × ID 12, against the cap ceiling.
It bears on the board's r 6–8 zone: on the parts there (0.5–1.1 mm, Q1 at
worst, 66 % local squeeze) and just on bare board (11 %). Holder heights from
3.79 mm (foam leaves bare board) to 4.19 mm (the ceiling reaches S1) assemble,
so a wrong holder reading is fixed by changing foam, not by reprinting.

**Geometry from the manufacturer STEP (2026-09-23).** The rev A ring was OD 25 ×
ID 16 × 1.0 over a 2.0 mm "board", both from a caliper. The Holyiot STEP
(`cad/board_holyiot_25008.py`) showed the board is **0.81 mm** with parts up
to **1.60 mm** (the tactile switch S1, dead centre), so the old ring hung
1.1 mm above the board face and held nothing, and its r 8–12.5 band sat
**right on the LED** (r 8.78–10.91). The ring moved inboard, under the opaque
core, and doubled in thickness. The ceiling did not move: z 6.60 closed over a
real board on revision A, and leaves **0.19 mm over S1**.

Ring rather than disc: the switch sits inside the ID. A cap pressing S1 is the
failure to watch for if the holder turns out taller than 4.0 mm.

### 6. Battery retention comes free

At the tangent point the cell edge is flush with the PCB edge, so the cavity wall
sits directly against the cell and blocks the direction it would slide out. With
the holder now facing down, the cavity floor also backs the cell face, pressing
it into its clip. No retention feature was added because none is needed.

### 7. In-plane side tabs for the harness

Two flat tabs in the plane of the base, each with a transverse slot and a bar at
the tip that the elastic wraps. The tag's **underside is completely flat** —
verified at 0.000 mm³ of material below the floor plane.

This replaced under-floor bridges, which stood 2.8 mm proud of the base. Losing
them took the assembled height from 11.50 mm to **8.70 mm**; the tabs widen the
tag to 40.14 mm across.

The tab root is only as thick as the base flange (1.2 mm), because above that
and inside the cap radius the space belongs to the rotating cap skirt. That root
carries harness load in tension, not bending, across 13 mm of width — so the
thin section is not the weak point it looks like. **Untested under load.**

### 8. Customer cap: clear shell, big coin lettering, accent core

`cad/cap_marking.py <number>` generates the per-hen cap as three bodies for
three filaments, delivered as a pre-registered Bambu project
(`cap_<n>_P1S.3mf`, slots 1/2/3 pre-assigned) plus a vendor-neutral 3MF:

| Body | Filament | What it is |
|---|---|---|
| `cap_<n>` | **clear PETG** | the whole shell — closure, seal, envelope untouched |
| `marking_<n>` | text colour | number (bottom arc, 6.0 pt), message (top arc, 5.2 pt caps), icon — 0.64 mm flush inlays |
| `core_<n>` | accent colour | full disc Ø17.2, the icon cut from it — colours meet edge to edge |

Two print trials shaped this. The first (opaque shell + clear LED ring)
proved the three-colour registration and the thread but the 2.9 mm lettering
was unreadable. The second revision makes the whole shell clear: the LED
(r 10.0, angle uncontrolled) shines through wherever it lands, so the window
part and every angular-alignment concern disappear, and the lettering band
grows to ~6 mm — letters twice the printed height, messages capped at
**8 guaranteed / ~12 typical characters**. The generator is deterministic
(fixed fonts, byte-identical output for identical input) and tested by a
29-case suite: envelope, rejections, determinism, full Bambu export.

---|---|---|
| `cap_<n>` | customer's cap colour, opaque | the shell — closure, seal, envelope untouched |
| `marking_<n>` | customer's text colour | coin-style lettering + centre heart, a 0.64 mm flush inlay |
| `window_<n>` | clear PETG | a **3.0 mm wide clear ring at r 10.0**, through the whole top plate |

Because the cap prints top-plate-down, all three meet in the first layers
against the plate: the outer face is one smooth plane, the id reads correctly
from outside, and the window is flush on both faces. The marking never reaches
the cavity (0.46 mm of shell above it); the window does, which is the point.

**Why a ring.** The LED centre sits at r 9.84 (manufacturer STEP; the caliper
said 10.0), at −60° in the body frame. Its *angle* relative to the cap is not controlled —
the board can turn a few degrees in its pocket, and the cap's stop angle
carried print tolerance at 360° per millimetre of thread pitch (the bayonet
ramp brings that down to about 4° per 0.05 mm, decision 9) — so a local window
would need bench-proven angular registration. A ring at the LED radius lights
wherever the LED is and needs no alignment at all. Its width only has to
cover the radial tolerance chain, which is small and known:

| Term | ± mm | Source |
|---|---|---|
| board radial play in the cavity | 0.30 | `fit_board` |
| cap concentricity, set by the seal bore | 0.10 | `fit_seal_r` |
| LED emitting-area half-size | ~0.8 | 0606–2020 package, UNVERIFIED |
| **half-width needed** | **1.2** | → 2.4 mm minimum ring |

The default is **3.0 mm** (r 8.5–11.5): 0.3 mm margin each side and ~7
extrusion widths, so the colour boundary prints crisp. Narrower does not buy a
larger id — at 2.5 mm the "67 ♥" sample is still 75 %, only the margin drops
to 0.05 mm. `--ring-width` overrides; `--pill R THETA` gives the old local
window for a cap whose registration has been proven on the bench.

**Coin-style lettering.** The id no longer sits in the centre: it bends along
the opaque band outside the clear ring (r 12.5–15.4), like the lettering on a
coin — the id along the bottom arc with glyph tops toward the centre, an
optional per-customer message (`--top "Szeretlek Bözsi!"`) along the top arc
with tops outward, both reading left to right, the gaps falling on the tab
axis. The centre inside the ring carries only the heart (`--no-heart` to omit).
Fonts are fitted automatically: the largest size whose bent, dilated glyphs
stay inside the band wins (the sample lands at 3.4 pt for the id, 3.2 pt for
the message, thinnest feature 0.72 mm after the 0.2 mm dilation that makes
hairline strokes printable). A message longer than ~200° of arc is refused
rather than shrunk into illegibility.

**What the ring costs.** The shell's central disc is joined to the rest of the
shell only through the clear ring — fine for printing (same PETG, different
pigment, fused in place) but worth knowing. The foam ring cannot stay at the
rim, which is exactly the LED radius: it moves inboard to **OD 16 / ID 12**,
where it bears on the board's r 6–8 zone. Whether that zone is free of tall or
pressure-sensitive parts is **unverified**; the tactile switch near the centre
is inside the ID.

`--no-window` reproduces the earlier two-body transparent cap.

### 10. Per-hen customisation: patterns, catalog, batch plates

Patrons choose a colour scheme (text + accent filament over the clear shell),
an icon *or* a centre pattern, and a top-band pattern; the serial number is
always on the cap. Everything a patron may choose is in `cad/catalog.json`,
mirrored in the app. Locked designs are batched one scheme per plate, 6 × 6
on the P1S, by `cad/cap_batch.py`; a 36-cap plate slices to 36 objects in an
estimated 4 h 13 m (`docs/lab/2026-09-14-cap-batch-plate.md`, **no plate
printed yet**). Design, constraints and the chirp-side requirements:
`docs/superpowers/specs/2026-09-14-hen-cap-customisation-design.md`.

### 9. Bayonet, not a thread

Revisions A/B closed with a Tr28.6 × 1.0 trapezoidal thread. One pair printed
and mated on 2026-08-28; the caps printed since tore along the thread and the
operator reported the flanks as "too steep". Computed from the revision B
`Params`, the thread was never inside what a 0.4 mm nozzle can lay down:

| Feature | Rev B thread | Why it tears |
|---|---|---|
| flank angle from horizontal | 15° | a 75° overhang; each ridge is a 0.55 mm shelf ~3 layers tall |
| male crest width | 0.35 mm | below one 0.40 mm extrusion |
| cap (female) crest width | **0.05 mm** | (1.0 − 0.647) − 2 × 0.15: a knife edge, hanging downward once the cap is flipped for printing |
| cap ridge root width | 0.35 mm | the whole ridge is thinner than one extrusion at its base |

The replacement is a three-lug bayonet, sized so that on **both** parts, in
their print orientations, nothing needs support. (Revision D, 2026-09-24:
the bearing faces were a 0.50 mm flat plus a 50° chamfer, and the flat under
each cap lip -- plus the 1.07 mm flat lower flank of the O-ring groove -- drew
slicer support. Both are now pure 50° cones; with support enabled Bambu
Studio generates none, on any of the four parts.)

| | Body | Cap |
|---|---|---|
| Feature | 3 lugs on the seal band, 20° × 0.80 mm proud, z 1.80–3.10 | 3 L-channels: 28° entry slot at the skirt's open end, then a 51° leg under a ceiling at z 3.40 |
| Bearing face | underside: a 50° cone from the bore radius to the crest (0.10 mm flat against the band) | lip top: the same 50° cone, bore to channel root |
| Overhang when printed | 50°, self-supporting (body prints upright) | 50°, self-supporting (cap prints top-plate-down, the lips hang from the skirt) |
| Load path | lug sheared at its root, 3 × 4.8 × 0.8 mm | lip in bending, 1.4–2.0 mm thick; 10.4 mm² projected cone-on-cone contact |

Both bearing faces are **helical at the same pitch** (12 µm per degree of cap
rotation, 2.7° helix angle), so they meet face to face rather than edge on
face. Turning the cap clockwise runs the lugs up the lips; after 30° the
flats meet and every further degree wedges the cap 12 µm harder onto the
base flange — the same hand-tight-to-the-stop feel the thread gave, and
self-locking (2.7° is far below PETG's ~11° friction angle). The ramp keeps
rising to 55° of travel, so a part that prints 0.36 mm tight or 0.30 mm loose
still locks, just at a different angle. Angular repeatability of the locked
cap improves from 18° per 0.05 mm of stop-face error (1.0 mm pitch) to about
4° per 0.05 mm.

What did not change: the radial seal and its groove, the cap OD (31.94 mm),
the grip scallops, the tabs, the lettering and LED ring, and the assembly
rule of decision 2. `cap_marking.py` and the accessory-platform proposal
inherit the new skirt untouched. The thread code is gone from the source
(and with it the `bd_warehouse` dependency); commit `e3cf940` has it.

**UNVERIFIED in fit.** The coupon pair has been printed once — dimensions
good, lock-up angle not yet reported (lab note 2026-09-10, print trial 1).
The coupon pair (`coupon_body`, `coupon_cap`) carries the lugs, the channels and the
groove at the real parts' z stations; the print trial's two questions are
whether the cap drops on at the entry slots and at what angle it locks up.
That angle re-tunes `cam_lock`.

---

## Bill of Materials — non-printed

| Item | Spec | Status |
|---|---|---|
| O-ring | NBR, **ID 26.74 × CS 1.50 mm**, closest stock size | to source |
| Foam ring | closed-cell PE/EVA, adhesive backed, **2.0 mm, OD 16 × ID 12** — a rim ring would sit on the LED | to source or punch |
| Clear PETG | third filament for the LED window; the cap shell and id are now opaque colours | per print |
| Elastic | 8 mm figure-eight harness | cross-section UNVERIFIED |
| Conformal coating | acrylic, per `docs/requirements.md` masking rules | unchanged |

> The previously specified 30 × 2 mm ring **does not fit this geometry**. Sourcing
> it would be wasted money.

---

## Print Settings

| Setting | Value | Why |
|---|---|---|
| Material | Transparent PETG | UV/impact per README; LEDs stay readable |
| Nozzle | 0.40 mm | thinnest wall in the design is 0.80 mm = 2 perimeters |
| Layer | 0.16 mm | the lip ramps and the O-ring groove need the resolution |
| Perimeters | 3 | the bayonet lips make the skirt 5 lines thick in places; 3 walls + gap fill |
| Wall generator | **Arachne** | variable-width walls absorb the lips as walls, not as infill islands |
| Avoid crossing walls | **on** | routes travels over the print instead of across the open bore — see *Stringing* below |
| Infill | 30 %+ | parts are nearly all perimeter anyway |
| Supports | **none** | verified by slicing; see below |
| Orientation | **already baked into the STLs** | drop them on the plate as-is |

`cad/out/hen_tag_revC_P1S.3mf` (from `slice_check.py --project`) carries all
four printables and these settings as a Bambu Studio project.

The exported STLs lie in their print orientation: the body floor-down, the cap
and the female coupon flipped top-plate-down. Do not re-orient them. Left as
modelled, the cap lands opening-down and its top plate becomes a ~28 mm bridge
over the cavity. The STEP files keep the design coordinate system, so the model
stays readable in CAD.

Revision B was sliced with Bambu Studio 02.08.02.60 at default settings: all
four parts returned `Success.` with **zero warnings** and
`max_cantilever_dist = 0` for the body. Revision C slices clean in the same
version, no warnings on any part; `cad/slice_check.py` repeats that check
from the command line and also reads the G-code back for the item below.

**Stringing is a toolpath property, not a geometry one.** In every layer of
the lip zone the skirt is a thin wall carrying three thicker arcs separated
by the entry slots, so the slicer prints three islands per layer and travels
between them. Left to the stock profile it flies straight across the open
bore and PETG leaves a hair on every pass; the first printed coupon showed
exactly that (lab note 2026-09-10, print trial 1). Measured on the G-code —
travels longer than 3 mm passing within 12 mm of the axis over open air:

| Part | stock Bambu profile | 3 walls + Arachne + avoid crossing walls |
|---|---|---|
| `coupon_cap` | 58 | **3** |
| `cap` | 107 | **19** (layer changes) |
| `coupon_body` | 96 | **0** |
| `body`, across the cell pocket | 102 | 68 |

The revision B threaded cap measured 106 on the stock profile, so this is
not a cost of the bayonet; it was always there, hidden inside a closed cap.

The coupons (`coupon_body.stl` 1.70 g, `coupon_cap.stl` 1.22 g) carry the
bayonet pair and the groove and nothing else, at the real parts' z stations.
**The bayonet fit has not been printed anywhere yet**, so print the pair
first. If the cap locks up well before 30° the parts are tight; if it reaches
the end wall still loose they are slack — either way report the angle and
change `cam_lock` (or `fit_lug_r` if the lugs bind radially) in the source and
regenerate; do not file the parts.

---

## Assembly

1. Conformal-coat the PCB per `docs/requirements.md`, masking SWD pads, battery contacts and
   the antenna area.
2. Seat the CR2032 in the holder, sliding it in at the tangent edge.
3. Drop the board into the body cavity **holder first, PCB facing up**. The
   holder should drop into its pocket with about 0.25 mm of play, and the PCB
   face should end up about 1.8 mm below the cap ceiling (0.19 mm over the
   centre switch).
   - Check the LED is facing you. If the PCB is against the floor, the board is
     upside down and the LED will be pointed at the bird.
4. Stick the OD 16 × ID 12 × 2.0 mm foam ring centred on the cap ceiling,
   under the core disc; the centre switch stays inside its hole.
5. Fit the O-ring into the cap's internal groove.
6. Turn the cap about 30° anticlockwise from its final position so the entry
   slots sit over the three lugs, press it straight down over the seal band
   until the skirt meets the base flange, then turn it clockwise until it
   stops turning freely — about 30°. Hand-tight is enough; the ramp is
   self-locking and the radial seal does not need more.
7. Thread the elastic through each side tab's slot and back around the bar.

---

## Verification Performed

`cad/verify.py`, 39 machine checks (48 with `--board-step`), all passing. Notable ones:

- body/cap collision: **0.000 mm³** at the assembled position
- board vs. enclosure interference: **0.0000 mm³**
- holder circumference backed by plastic: **100 %**
- fill clears the PCB face: 0.20 mm
- clearance at the tangent point: **0.30 mm**
- cap drops on at the entry angle and the lugs run free for 0–28°: **0.000 mm³**
  overlap at every step
- ramp wedges past the lock angle: **0.498 mm³** interference at +4°, the cap tightens
- locked cap retained: **6.08 mm³** lug/lip overlap when lifted 0.6 mm; at the
  entry angle it lifts off clean
- cap bore clears the seal band: +0.10 mm (the rule that caught decision 2)
- O-ring never crosses the lugs: groove starts z 3.91, channels end z 3.40
- slicer support with support enabled: **none** on body, cap and both coupons (Bambu Studio CLI)
- O-ring squeeze: **22 %** (static radial target is 15–30 %)
- thinnest wall: **0.80 mm** under the grip scallops
- 8.0 mm elastic threads the tab slot: **0.000 mm³** obstructing
- tab bar cross-section: **4.80 mm²**
- underside flat: **0.000 mm³** below the floor plane
- assembled envelope: 40.14 × 31.94 × 8.70 mm
- worst unsupported overhang band: **3.03 mm²** on the body (the lugs' bearing
  flats), 96.33 mm² on the cap (the O-ring groove flank, which becomes a
  ceiling once the cap is flipped; unchanged since revision A). The cap's total
  fell from 242 to 115 mm² with the thread gone.
- meshes watertight: 0 non-manifold edges, 0 loose vertices, positive volume
- **sliced clean in Bambu Studio** (revision C, 2026-09-10): all four parts,
  zero warnings; open-air travels with the recommended settings: cap 19,
  coupon 3, body 0 above the fill (`cad/slice_check.py`)

### The floating-cantilever defect

The rim's lead-in chamfer was cut with a cone tapering the wrong way. Instead of
narrowing toward the rim it widened, which thinned the wall to a **0.10 mm knife
edge** low down and left a downward-facing annular shelf above it — a genuine
undercut, and unprintable.

Confirmed by slicing both versions:

| | `max_cantilever_dist` | Slicer verdict |
|---|---|---|
| Inverted chamfer | 1.37 × 10⁶ | *"floating cantilever… enable support generation"* |
| Corrected | **0** | `Success.`, no warnings |

A second, smaller floating feature was found in the same pass: the thread began
0.2 mm above the base flange, leaving its first ridge unsupported. The thread now
starts flush on the flange, which took the body's worst overhang band from
18.95 mm² down to 9.36 mm² (revision B; with the thread replaced by the bayonet in
revision C it is 3.03 mm²).

`verify.py` now measures unsupported overhang area per part against limits
calibrated to revision A, which is known to print, so this class of defect
cannot return unnoticed.

Mesh volume matches the solid model to within 0.3 mm³, so STL tessellation is
not distorting the geometry.

**What revision A proved**: printed on a Bambu Lab P1S, dimensions and thread
fit both confirmed good on physical parts.

**What none of this proves**: the bayonet's fit. The coupon pair has been
printed once (dimensions good, lock-up angle not yet reported); the full cap
has not been printed. No O-ring has been compressed, no water
has touched it, no elastic has loaded a tab, and no hen has worn it.

---

## Verified Evidence vs. Working Hypotheses

### Verified

- **Revision A printed and fitted on a Bambu Lab P1S: dimensions good; the
  thread mated on that one pair.** Later caps tore along it (lab note
  2026-09-10), so the thread and its clearances are history. What carries over
  as empirical is the cavity, the seal band and the skirt.
- The geometry is internally consistent, manifold, and assembles without
  interference **given the assumed inputs**.
- The internal tangency of PCB and holder follows from the two reported
  diameters and matches the operator's description.
- The mass comparison between sealing strategies is computed from real solids,
  not estimated.
- **Board and parts from the manufacturer STEP** (`HOLYIOT-25008-V1.0.step`,
  2026-09-23): Ø25.00 × 0.81 board, S1 1.60 tall at the centre, LED at r 9.84 /
  −60°, nothing beyond r 11.77. `verify.py --board-step PATH` re-extracts
  the numbers and collides the real board with body and cap (0.0000 mm³).
  The STEP's battery clip is a generic model (it leaves 2.39 mm for a 3.2 mm
  cell) and is ignored.

### Assumed (UNVERIFIED)

- Holder Ø21 × 4.0 mm (caliper). Board stack 6.41 mm follows from it; the
  ceiling tolerates a holder of 3.79–4.19 mm.
- Board part mass 0.18 g (volume at an assumed 2.5 g/cm³); holder mass 0.6 g and O-ring mass 0.4 g, both estimates that the 10 g budget
  argument depends on.
- Elastic cross-section fitting an 8.6 × 2.0 mm channel.
- The bayonet fit: `fit_lug_r` 0.15, `fit_lug_z` 0.30, lock-up at 30°. Modelled,
  no coupon printed.

### Unknown

- Antenna location. Probably a printed antenna: the matching network
  (L3/L4/C8–C13) sits beside the radio at 115–136°, and the rim from 141° to
  290° carries no parts. The STEP has no copper, so this stays unconfirmed; the
  enclosure puts no metal anywhere near the board.

---

## Open Questions & Next Steps

1. **Print the bayonet coupon pair** and report whether the cap drops on at
   the entry slots and at what angle it locks up (nominal 30°, usable 5–55°);
   that angle re-tunes `cam_lock`. Then the full cap: that the LED is actually
   visible through the Ø16 foam window, and that a tab survives being loaded
   with an elastic. The revision B body has already accepted the board.
2. **Measure the total stack height** in one caliper span and the assembly mass
   on a scale. Both feed straight back into `Params`.
3. **Source the O-ring** at ID 26.74 × CS 1.50 mm, or report the nearest stock
   size available so the groove can be re-cut to it.
4. **Mass**: revision B lands 0.89 g over a 10 g target, up from 0.19 g, because
   the cell fill costs about 0.7 g. Roughly 1.0 g of the total is still
   estimated rather than weighed. If the weighed figures confirm the overrun,
   the cheapest reductions are lightening the fill in its thick sector, the cap
   top plate, and the base flange — but a decision on whether 10 g is a hard
   welfare limit or a design aspiration should come first.
5. **No ingress rating is claimed.** IP54 remains an intent, not a test result.

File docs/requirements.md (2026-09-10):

# Hen Tag Physical Enclosure & Ingress Protection

## Purpose & Status
This document specifies the mechanical design criteria, material selection, sealing mechanisms, and PCB coating procedures for the active hen tag enclosure.
- **Status**: Revision C (bayonet closure). Parametric CAD generated and
  machine-verified. **Revision A was printed and fitted on a Bambu Lab P1S —
  dimensions good; its thread mated on that pair, but later caps tore along it,
  so revision C replaced the thread with a bayonet (UNVERIFIED, no coupon
  printed). A revision B body was also printed and accepted the board; the cap
  and complete sealed assembly remain untested.**
- **Source of truth for geometry**: [`DESIGN.md`](../DESIGN.md) and `../cad/hen_tag_enclosure.py`. Where this document and `DESIGN.md` disagree on the sealing arrangement, `DESIGN.md` is current — see "Sealing" below.
- Board dimensions remain operator caliper readings with one unresolved ambiguity: [`docs/lab/2026-08-28-enclosure-board-measurements.md`](lab/2026-08-28-enclosure-board-measurements.md).

---

## Mechanical Specifications & Design Decisions

```
+-----------------------------------------------------------------------------+
| TWO-PART BAYONET-CAP ENCLOSURE, REV C    Assembled: 40.14 x 31.94 x 8.70 mm |
+-----------------------------------------------------------------------------+
|                            O31.94                                           |
|              +------------------------------+   Transparent PETG cap        |
|              | ---  O16 LED window  ---     |   foam recess 0.30            |
|         =====+==============================+=====  ceiling z=6.60          |
|              | :::                :::       |   foam RING OD25/ID16 x 1.0   |
|              | ####### PCB O25 ####### z=6.0|   <-- LED faces the cap, i.e. |
|         O----+ ####################### z=4.0+----O   away from the bird     |
|              |***+--------------------+*****|   O-ring ID 26.74 x CS 1.5    |
|              |***|  CR2032 + holder   |*****|   radial, seals on r=13.70    |
|    ##########+***|  O21, offset 2.0   |*****+##########  bayonet, lugs low  |
|    +-----+   |___+--------------------+_____|   +-----+  BELOW the seal     |
|    |  o  |===|   *** = fill that holds the holder |  o  |===  in-plane tabs |
|    +-----+   +------------------------------+   +-----+   slot 8.8 x 1.8    |
|                     FLAT UNDERSIDE                        bar 1.5           |
+-----------------------------------------------------------------------------+
```

### 1. Material Selection
- **Enclosure Body & Cap**: Transparent PETG (Polyethylene Terephthalate Glycol).
  - *Rationale*: PETG provides superior impact resistance, UV stability, low moisture absorption, and excellent layer adhesion compared to PLA.
- **Strict Prohibition on Conductive Filament**:
  > [!IMPORTANT]
  > Under no circumstances may carbon-fiber filled or conductive filaments be used. Conductive additives detune the 2.4 GHz PCB antenna and create electrostatic discharge / shorting hazards with exposed coin cell terminals.

### 2. Sealing & Water Ingress Protection

> [!IMPORTANT]
> **Superseded.** The axial face seal below was replaced by a **radial** seal
> during CAD. A face seal must sit outboard of the cap skirt, forcing a Ø36 mm
> flange around a Ø25 mm board — measured at 11.88 g assembled against a 10 g
> target. The radial seal needs no flange and lands at 10.19 g.
> The ring size changed with it: **ID 26.74 × CS 1.50 mm**, not 30 × 2 mm.
> Do not order the 30 × 2 ring. Rationale and the measured comparison are in
> [`DESIGN.md`](../DESIGN.md).

- **Gasket (current)**: NBR O-ring, ID 26.74 × CS 1.50 mm, 22 % squeeze.
- **Sealing Mechanism (current)**: Radial seal in a groove in the cap bore,
  compressed against a plain band on the body. Compression is set by the bore
  diameter, so it does not depend on how hard the cap is tightened — which is
  what the superseded design needed a stop flange to control.
- **Closure**: Three-lug bayonet — 0.80 mm lugs on the body, self-locking
  helical ramps in the cap, 30° clockwise to lock — positioned **below** the
  seal so the O-ring never crosses the lugs. Replaced the Tr28.6 × 1.0 thread
  on 2026-09-10 after caps tore along it; see
  [`DESIGN.md`](../DESIGN.md#9-bayonet-not-a-thread) decision 9 and
  [`docs/lab/2026-09-10-thread-print-failure.md`](lab/2026-09-10-thread-print-failure.md).
  UNVERIFIED in print.
- **Target Ingress Rating**: Realistic IP54-level dust and splash protection.
  No certified ingress rating is claimed, and none has been tested.

<details>
<summary>Original face-seal specification (historical)</summary>

- **Gasket**: NBR O-ring, nominal dimensions around 30 x 2 mm.
- **Sealing Mechanism**: Axial face-seal compressed by a threaded screw cap with defined stop-flange to prevent O-ring over-compression or shearing.

</details>

### 3. Conformal Coating Protocol
To protect bare board traces from moisture condensation and corrosive ammonia vapours:
- Apply a thin acrylic conformal coating across the Holyiot 25008 PCB.
- **Mandatory Masking Zones**:
  - SWD programming pads / test points (for future firmware flashing and debugging).
  - Battery holder spring contacts (positive leaf and negative base pad).
  - 2.4 GHz PCB trace antenna (preferably masked to avoid dielectric loading and RF detuning).

### 4. Form Factor & Battery Fitment
- Designed specifically around the Holyiot 25008 module with integrated CR2032 coin cell holder.
  > [!NOTE]
  > Historical or experimental concepts utilizing CR2477 cells are **stale** and superseded. The active enclosure volume is strictly sized for CR2032 cells.

---

## Verified Evidence vs. Working Hypotheses

### Verified Evidence
- Holyiot 25008 board with CR2032 battery holder physically observed on test bench.
- PCB and holder are **internally tangent**: the cell edge is flush with the PCB edge at one point. Confirmed geometrically from the reported Ø25 and Ø21 diameters (2.00 mm centre offset, 0.0000 mm edge gap).
- **Revision A printed on a Bambu Lab P1S — dimensions good; its thread mated on that pair.** The thread has since been replaced by the revision C bayonet after later caps tore along it (`docs/lab/2026-09-10-thread-print-failure.md`). See [`docs/lab/2026-08-28-enclosure-print-trial.md`](lab/2026-08-28-enclosure-print-trial.md).
- Revision B geometry is watertight and assembles without interference — 29
  machine checks in `../cad/verify.py`, all passing, and all four parts slice clean
  in Bambu Studio. Its printed body accepted the board in the intended
  component-up orientation. The revision B cap, sealed assembly and load path
  remain physically untested.

### Key Decisions
- Two-part transparent PETG bayonet cap with a **radial** NBR O-ring (ID 26.74 × CS 1.50 mm). The 30 × 2 mm face-seal ring is superseded.
- Closure positioned below the seal, so the cap can actually be assembled and the O-ring never crosses it. Revision C's closure is a bayonet; the thread it replaced tore in print.
- **Holder faces down toward the harness, PCB faces up.** The LED is on the PCB and must be readable through the cap rather than pointed at the bird.
- **Fill around the cell** so the body itself retains the holder: 100 % of the holder circumference is backed by fill or by the cavity wall.
- Board clamped by a foam **ring** (OD 25 × ID 16 × 1.0 mm) on the PCB rim, leaving a Ø16 LED window. Ring, not disc, so the LED stays visible.
- **Harness moved to in-plane side tabs**; the underside is now completely flat and the assembled height dropped from 11.50 mm to 8.70 mm.
- Masked conformal coating applied before field deployment.
- No antenna keep-out designed. The antenna could not be located, and inventing a zone would breach the no-invented-hardware rule.

### Open Questions & Next Steps
1. **Print the revision C bayonet coupons, then the cap and complete assembly.** The body/board
   fit is observed, but the model cannot prove cap fit, LED visibility through
   the current clear-shell/inlay design, sealing, or that a tab survives an
   elastic under load.
2. **Total stack height** in one caliper span, board bottom to seated cell top. Resolves the ambiguity the CAD currently assumes past.
3. **Weigh the assembly**: bare board, holder, cell. Revision B models at 10.92 g against the ~10 g target, and about 1.0 g of that is estimated rather than measured.
4. **Source the O-ring** at ID 26.74 × CS 1.50 mm, or report the nearest stock size so the groove can be re-cut.
5. **Elastic cross-section**: the tab slot is cut 8.8 × 1.8 mm on an assumption.

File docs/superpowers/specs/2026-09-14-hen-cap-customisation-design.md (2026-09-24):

# Hen Cap Customisation — Design

- **Date**: 2026-09-14
- **Status**: built. Generator side (§6) and editor prototype (§7) on branch `feat/cap-customisation` of this repo; chirp side (§8) merged on 2026-09-14 as https://github.com/Remeny-Farm/chirp/pull/2409 (ADR-0244). See *Outcome* at the end.
- **Scope of this repository**: the generator changes, the batch CLI, the
  catalog manifest, the preview layout export, and a browser-testable
  prototype of the patron editor built with chirp's own UI library. The chirp
  side (tables, endpoints, admin pages) is specified here as requirements and
  is implemented in the chirp repository only on explicit instruction.

---

## 1. Purpose

Patrons of a real hen edit their hen's 3D-printed tag cap in the app: they
choose one of three preset colour schemes (some cost Golden Grain), an icon or
a centre pattern, and a top-band pattern. The hen's serial number is always on
the cap. They preview it live, then **lock** it. Staff batch the locked caps
of one colour scheme onto one printer plate — as many as fit — generate the
print file on the farm Mac with one command, print, and install. A patron can
re-edit a locked cap for a fee before it is batched, and later request a
physical replacement for a larger fee.

## 2. Decisions taken

| Question | Decision |
|---|---|
| Free text on the cap | **No.** Serial number plus icon/pattern only. The generator keeps `--top` for staff use; the patron editor never exposes it. |
| Where the CAD generator runs | **On the farm Mac, by CLI.** No server-side CAD, no CI job. |
| How a batch reaches the Mac | **Admin downloads a batch JSON; the CLI consumes it.** The CLI never talks to the API. |
| Preview | **Live SVG in the app**, drawn from a layout export of the generator. The authoritative CAD render (proof) is produced with the batch and uploaded by staff. |
| After lock | Patron may re-edit for Golden Grain while the design is not yet batched. After installation a replacement can be requested for a larger fee (someone has to catch the hen in the evening and swap the cap). |
| Pattern zones | Two independent choices: **centre** (icon *or* pattern inside the inner disc) and **top band**. Packs: *basic* (free), *vibe* (30 grain), *drop* (80 grain, limited) — 26 icons, 3 centre and 13 band patterns as of 2026-09-14. |
| Colours | A scheme is a fixed **base** filament (the whole cap) plus two free colours **a** and **b**; the fourth AMS slot is always Clear for the LED window. The patron assigns base / a / b to each of five zones of the top plate (outer ring, number, inner disc, centre element, band pattern). Rules: number ≠ ring, centre ≠ disc, band ≠ ring. Only the top plate (7 layers) changes colour. |
| Editor | Built **here** as a drop-in component using `@chirpcoop/real-chicken-ui` and `@chirpcoop/design-tokens`, testable in a browser from this repo; merged into chirp only on instruction. Web patron surface first (`apps/web/(patron)`); the mobile runtime reuses the same component library, so it can adopt it later. |

## 3. Physical and printability constraints (facts the design is built on)

- The cap shell is the scheme's **base filament**; a **clear annulus
  r 8.5–11.5 through the whole top plate** is the LED window (AMS slot 2).
  Slots 1 / 3 / 4 are base / a / b. A 4-slot AMS holds **one scheme per
  plate**; a design only decides which of the three a zone gets.
- The number sits entirely outside the window: Verdana **4.5 pt** (3.4 mm
  digits, 3.8 mm with the 0.18 mm dilation) in the band r 11.6–15.4.
- Plate: Bambu Lab P1S, 256 × 256 mm, front-left exclusion 18 × 28 mm.
  Grid **6 × 6 = 36 caps** at 36 mm pitch, origin (20, 8) mm — clear of the
  exclusion zone. Hex packing would reach ~42; not done in v1.
- Colour changes happen only in the first 4 layers (the 0.64 mm inlays), so
  a full plate costs the same number of filament changes as one cap.
  Estimated ~10 min per cap, a full plate is an overnight print.
  **Estimate; the plate is sliced by `slice_check.py` before the first print.**
- Serial numbers: 1–5 digits (`real_chickens.serial`) on the bottom arc. Font
  and size are fixed; the patron does not choose them.
- Inlays: 0.64 mm deep, flush with the outer face, minimum printable feature
  0.58 mm (0.8 mm for patterns, with ≥ 0.8 mm gaps). Every inlay island is
  one connected solid.
- LED ring r 8.5–11.5 mm: the number already covers part of it; patterns must
  leave **≥ 60 %** of the ring's area clear (generator check). Centre patterns
  live inside r ≤ 8.6, band patterns in r 11.5–15.4 unless sparse.
- Icons and patterns are **parametric code** (`cad/cap_motifs.py`), not fonts
  or uploads; `cad/check_motifs.py` proves every one printable (erosion and
  dilation tests, extents). Adding one is a sketch function plus a catalog
  entry.
- Determinism: identical inputs give byte-identical files. A locked design is
  fully described by its inputs plus the generator version.

## 4. Catalog

One catalog, two copies kept identical by a test:

- **chirp**: code constants (like the hen traits), shipped to the client and
  validated server-side at lock.
- **this repository**: `cad/catalog.json`, the source of truth for the
  generator; `test_cap_marking.py` fails when its keys differ from the
  generator's `ICONS` / `PATTERNS` tables.

```json
{
  "schema": "hen-cap-catalog/1",
  "generator_version": "<git sha>",
  "schemes": [
    {"id": "classic", "name": {"hu": "Klasszikus", "en": "Classic"},
     "text": {"filament": "Bambu PETG Basic Black", "hex": "#1a1a1a"},
     "accent": {"filament": "Bambu PETG Basic White", "hex": "#f2f2f2"},
     "price_grain": 0}
  ],
  "icons": [{"id": "heart", "name": {"hu": "Szív", "en": "Heart"}}],
  "centre_patterns": [{"id": "rings", "name": {"hu": "Körök", "en": "Rings"}}],
  "band_patterns": [{"id": "stripes", "name": {"hu": "Csíkok", "en": "Stripes"}}],
  "fees": {"reedit_grain": 50, "replacement_grain": 500}
}
```

The three schemes, their filaments and prices are **open** (§12); the shape
above is fixed. Hex values are physical filament colours used by the preview
and the proof; in chirp they live in a data asset, not in TS/CSS, so the
raw-design-value hook does not apply.

## 5. The batch contract (the only interface between the two sides)

`hen-cap-batch/1`, produced by the admin UI, consumed by `cap_batch.py`:

```json
{
  "schema": "hen-cap-batch/1",
  "batch_id": "2026-09-14-classic-01",
  "scheme": "classic",
  "generator_version": "71abeb5",
  "created_at": "2026-09-14T18:00:00Z",
  "caps": [
    {"serial": 67, "icon": "heart", "centre": null, "band": "stripes",
     "design_hash": "3f9c2a7b1e5d4c08", "hen_name": "Bözsi"}
  ]
}
```

- `icon` and `centre` are mutually exclusive; both `null` means a plain
  accent disc. `band` may be `null`.
- `design_hash` = first 16 hex chars of SHA-256 over the canonical JSON
  `{"band":"stripes","centre":null,"colours":{"band":"b","centre":"a","disc":"b","number":"a","ring":"base"},"icon":"heart","scheme":"pasture","serial":67,"v":2}`
  (sorted keys, no whitespace); every cap in a batch carries its `colours`. It covers the design only, not the
  generator version, so a generator release does not invalidate locked
  designs. Both sides compute it; the CLI refuses a cap whose hash does not
  match its fields.
- `generator_version` is the value the app took from the published
  `cad/catalog.json`; the CLI refuses a batch whose value differs from the
  catalog on the Mac, so a catalog change is always deployed to both sides
  before a batch crosses.
- Outputs, all named by the batch id and design hash so they can be matched
  back without a database:
  `plate_<batch_id>_P1S.3mf`, `plate_<batch_id>_manifest.csv`
  (position `1A`…`6F` = column number + row letter, serial, hen name, design
  hash), `proof/<design_hash>.svg`.
- The plate file does not carry the scheme's filament colours: Bambu Studio
  02.08 rejects a three-entry `filament_colour` on export (lab note
  2026-09-14). The AMS mapping 1 clear / 2 text / 3 accent is set on the
  printer from the catalog's filament names.

## 6. Generator side (this repository)

### 6.1 `cap_marking.py`
- `--centre <pattern>` (rings, solid, dots; exclusive with `--icon`) and
  `--band <pattern>` (stripes, dots, arc). Patterns are sketch functions in a
  `PATTERNS` table beside `ICONS`; band patterns go into the **core body**
  (accent colour), centre patterns into the **marking body** (text colour).
- New machine checks: pattern feature ≥ 0.8 mm and gap ≥ 0.8 mm, LED-ring
  clearance ≥ 60 %, no inlay touches another inlay of a different colour.
- `--layout-json out/layout.json`: band and core radii, font sizes, arc
  centres, `GAP_ARC`, the dilated outlines of digits 0–9 at 6.0 pt as SVG
  path strings with advances (mm), and every icon/pattern as an SVG path.
  This is what the app's live preview draws from, so the preview and the
  print come from the same numbers and no system font is needed on any
  device.
- `--proof out/proof/<hash>.svg`: top view of the cap in the scheme's colours
  from the exact 2D sketches (clear disc outline, accent ring, marking,
  patterns).
- `--top` stays for staff; it is not in the batch contract.

### 6.2 `cap_batch.py` (new)
1. Read and validate the batch JSON (schema, `generator_version` equal to
   the local catalog's, catalog keys, unique serials, hashes).
   Any failure refuses the whole batch and lists every offending cap.
2. Build each cap's three bodies, cached under `out/cache/<design_hash>/`
   so a re-run or a re-print costs nothing.
3. Place caps on the 6 × 6 grid in list order (row-major, deterministic).
4. Write the Bambu project with a **pure-Python writer** modelled on the
   CLI-exported projects in `out/` (`3D/3dmodel.model`, per-object meshes,
   `Metadata/model_settings.config` with part extruders 1/2/3 and plate
   positions, `Metadata/project_settings.config` with the P1S machine,
   0.16 mm process, PETG Basic and the three settings from `DESIGN.md`:
   3 walls, Arachne, avoid crossing walls). No dependency on the Bambu
   Studio CLI, so the writer also runs where the app is not installed.
5. Write the manifest and the proofs.
6. Run `slice_check.py` on the plate when Bambu Studio is present (open-air
   travel limit scaled by cap count, cantilever 0 on the shared plate check,
   slicer warnings) and print the slicer's time and filament estimates.

### 6.3 `slice_check.py`
Accepts a plate 3MF as input in addition to the four printables.

## 7. Patron editor (prototype built here, drop-in for chirp)

### 7.1 Component architecture (`editor/src/`)
- `CapEditor` — the page body: scheme picker, decor pickers, preview, price
  line, primary action. Props: `{ design, catalog, layout, wallet, copy,
  client }`. No data fetching inside; the page wrapper supplies a client.
- `CapPreview` — pure SVG from `layout.json` + design: clear disc, accent
  ring in the scheme's accent colour, digits placed along the bottom arc from
  the exported glyph paths and advances (same algorithm as the generator:
  centred on 270°, per-glyph advance), icon/centre pattern in text colour,
  band pattern in accent colour. Deterministic (INV-7 spirit).
- `SchemePicker`, `DecorPicker` — segmented option groups with 44 px tap
  targets, price badges via `GoldenGrainGlyph`, locked/paid affordances.
- `LockDialog` — confirmation with the price, the wallet balance
  (`GoldenGrainPill`), and the consequence text ("editing later costs X").
- `CapDesignClient` interface: `load(serial)`, `save(draft)`, `lock()`,
  `unlockForEdit()`, `requestReplacement()`, `getWallet()`. The prototype
  ships an in-memory mock with the full state machine and a fake wallet;
  chirp later supplies the SDK adapter.
- Copy: a `CapEditorCopy` object passed in (HU and EN provided), following
  the `RealChickenCopy` pattern; no string literals in the component.

### 7.2 Design states shown by the editor
`draft → locked → batched → printed → installed → replaced`
- draft: editable; primary action **Lock** (shows the scheme price if paid).
- locked: read-only preview; **Edit again** for the re-edit fee.
- batched / printed: read-only, "waiting for print / being printed"; the
  proof image appears once staff upload it.
- installed: proof, **Request replacement** for the replacement fee, which
  opens a new draft; the old design becomes `replaced` when the new one is
  installed.

### 7.3 Style and tooling rules the prototype already obeys
- Only `@chirpcoop/real-chicken-ui` components and `var(--rc-*)` /
  `@chirpcoop/design-tokens` values; no raw hex, px, rem in TS or CSS
  (the cap's filament colours come from the catalog data asset).
- Plain CSS file beside the component, `.rc-cap-*` class prefix, React 19,
  TypeScript strict, vitest + testing-library tests, English-only source.
- Harness: `editor/` is a Vite app whose `vite.config.ts` aliases
  `@chirpcoop/real-chicken-ui` and `@chirpcoop/design-tokens` to the chirp
  checkout's `src` (path from `CHIRP_DIR`, default `../chirp`), and imports
  `dist/tokens.css` and the package CSS. chirp is read, never written.
  `pnpm dev` serves the editor with the mock client; `pnpm test` runs the
  component tests. A single-file build can be published as an artifact for
  review on another device.

### 7.4 Integration map (executed only on instruction, in chirp)
| Prototype file | Lands in chirp as |
|---|---|
| `editor/src/cap-editor/*.tsx`, `*.css`, `*.test.tsx` | `packages/real-chicken-ui/src/cap-editor/` |
| `editor/src/copy/{hu,en}.ts` | keys in `apps/web/i18n/` catalogs |
| `editor/src/client.ts` (interface) + mock | interface stays; SDK adapter in `apps/web/lib/` |
| `editor/src/page.tsx` | `apps/web/app/(patron)/my-hen/cap/page.tsx` + client wrapper |
| `cad/catalog.json`, `cad/out/layout.json` | data assets under `packages/real-chicken-ui/src/cap-editor/data/` |

## 8. Requirements for the chirp side (for a chirp ADR)

- **Tables**: `hen_cap_designs` (chicken_id, serial snapshot, scheme, icon,
  centre, band, design_hash, status, locked_at, batch_id, proof_url,
  grain ledger refs, patronage interval ref); `hen_cap_batches` (scheme,
  generator_version, cap list, json_downloaded_at, printed_at,
  installed_at). At most one design per hen that is not `installed` or
  `replaced`. Patronage change → the open design is abandoned, a new draft
  starts; installed designs stay as history.
- **Endpoints** (server-authoritative, Zod in `shared-types`): get/save
  draft, lock (quote → atomic spend for a paid scheme, idempotent), unlock
  for edit (fee, only while `locked`), request replacement (fee, only while
  `installed`), get catalog; admin: list locked by scheme, create batch
  (≤ 36, FIFO by `locked_at`, sets `batched`), download batch JSON, upload
  proofs (file name = design hash), mark printed / installed.
- **Validation at lock**: scheme/icon/centre/band exist in the catalog,
  icon and centre exclusive, serial equals the hen's, design_hash recomputed
  server-side.
- **Admin UI**: scheme tabs, cap counts, "Create batch", "Download JSON",
  proof upload (folder), printed/installed buttons, replacement queue.
- **Invariants**: currency as `bigint`; no raw design values; English-only
  source; every state transition audited in the wallet ledger where it
  charges.

## 9. Error handling

- CLI: refuses a batch on schema/version/catalog/hash/duplicate errors with
  a complete list; partial plates (< 36) are normal; a cap whose CAD checks
  fail (should not happen for catalog inputs) stops the batch and names the
  cap.
- Editor: server errors map to copy keys by `code` (insufficient grain,
  design already batched, catalog mismatch); the preview never blocks on the
  network; lock is disabled until the draft is saved.
- Staff: a proof file whose name matches no design in the batch is rejected
  on upload.

## 10. Testing

- This repository: pattern printability and LED-clearance checks; catalog
  parity; `cap_batch.py` on a 3-cap fixture (byte-identical plate on two
  runs, manifest and proofs present, refusal cases); `slice_check.py` on a
  full 36-cap plate; editor component tests (state transitions, price and
  balance display, lock confirmation, preview determinism for a fixed
  design), plus a manual browser pass.
- chirp (later): endpoint tests for the state machine and idempotent grain
  spend; admin batch creation limits.

## 11. Out of scope for v1

Free text, custom uploads, per-icon pricing, hex packing, mobile runtime
screens, automatic proof upload from the CLI, server-side CAD.

## 12. Open questions

1. The three schemes: filament pairs and Golden Grain prices.
2. Re-edit fee and replacement fee.
3. Whether the band pattern should be offered in the text colour as well as
   the accent colour (v1: accent only).
4. Whether staff upload proofs from the admin UI or the CLI gets an optional
   upload later.

## Outcome (2026-09-14)

- **This repo**: catalog (`cad/catalog.json`: 3 Prusament schemes = base + two free
  colours + Clear window, packs basic / vibe 30 / drop 80 limited, 26 icons,
  16 patterns, five colour zones with rules, fees), `cad/cap_motifs.py` +
  `check_motifs.py`, four-body generator (base shell, clear LED annulus, colours
  a/b per zone; number 4.5 pt above the window), `cap_svg.py` layout/proof,
  `bambu_project.py` (four-filament template), `cap_batch.py` with a
  generator-fingerprinted cache; suites 77 / 9 / 15 green, a 36-cap plate slices
  to 36 objects in ~4 h 13 m. The `editor/` prototype was redesigned as a
  game-like three-step flow and scored 95/100 by an independent review
  (`editor/DESIGN-NOTES.md`); paging arrows on the rails were added last.
- **chirp** (PR #2409): ADR-0244, two migrations (`hen_cap_designs`,
  `hen_cap_batches`, `hen_cap_*` RPCs charging through `spend_hard_currency`),
  endpoint family `hen-cap` (6 patron + 6 admin functions), the editor in
  `packages/real-chicken-ui/src/cap-editor/`, web entry Account → "My cap"
  (`/account/cap`), Tyutyu app entry Settings → Real farm → "My hen's cap"
  (flag `henCapEditor`), admin `/hen-caps` batch page producing
  `hen-cap-batch/1`. Web deploy verified (HTTP 200 on both hosts).
- **Still open**: promote the two migrations and 12 functions to Supabase
  (manual lane) and create the public-read bucket `hen-cap-proofs`; print the
  first real plate; measure filament hexes on printed swatches; decide the
  Drop pack's expiry mechanism (`available_until` is not modelled yet).

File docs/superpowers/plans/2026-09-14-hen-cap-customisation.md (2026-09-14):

# Hen Cap Customisation Implementation Plan

> **For agentic workers:** REQUIRED SUB-SKILL: Use superpowers:subagent-driven-development (recommended) or superpowers:executing-plans to implement this plan task-by-task. Steps use checkbox (`- [ ]`) syntax for tracking.

**Goal:** Patrons design their hen's cap (scheme, icon or centre pattern, band pattern) in a drop-in React editor; staff batch one scheme's locked caps onto a 6 × 6 P1S plate with one CLI command.

**Architecture:** Part A extends the deterministic Python generator (`cad/`): a catalog manifest, pattern sketches, a layout/proof SVG export, a pure-Python Bambu project writer and a batch CLI driven by a JSON contract. Part B is a Vite + React 19 prototype (`editor/`) that consumes chirp's own UI package and design tokens from the chirp checkout by path alias, ships an in-memory client with the full design state machine, and is written so its files move into `packages/real-chicken-ui/src/cap-editor/` unchanged.

**Tech Stack:** Python 3.12 + build123d via `uv run`; Bambu Studio CLI (optional, for checks); TypeScript strict, React 19, Vite, vitest + @testing-library; pnpm.

**Spec:** `docs/superpowers/specs/2026-09-14-hen-cap-customisation-design.md`

## Global Constraints

- English only in code, comments, commit messages, docs; HU strings only inside copy catalogs (`editor/src/copy/hu.ts`) and the catalog's `name.hu` fields.
- Python: `# /// script` PEP 723 header with `dependencies = ["build123d"]`; run every script as `uv run --python 3.12 <script>`; wrap builds/tests in `dev-budget run --kind heavy -- ...`.
- Determinism: identical inputs → byte-identical files (canonical meshes, fixed zip timestamps `(2026, 1, 1, 0, 0, 0)`, deterministic UUIDs).
- Physical: inlay depth 0.64 mm; pattern feature ≥ 0.8 mm and gap ≥ 0.8 mm; LED ring r 8.5–11.5 ≥ 60 % clear; centre patterns r ≤ 7.4; band patterns r 12.0–15.0 inside the fixed window −10°…190°; number centred at 270°, Verdana 6.0 pt, uniform digit advance 3.814 mm.
- Plate: 6 × 6, pitch 36 mm, centres `38 + 36·i` on both axes, ≤ 36 caps, one scheme per plate; AMS 1 = clear, 2 = text, 3 = accent; project settings `wall_loops=3`, `wall_generator=arachne`, `reduce_crossing_wall=1`.
- Design hash: first 16 hex chars of SHA-256 over `json.dumps({"band","centre","icon","scheme","serial","v":1}, sort_keys=True, separators=(",",":"))`. Test vector: serial 67, classic, heart, band stripes → `05dcdb796b921b25`; serial 8, meadow, centre rings → `0371884d05cc4f6b`; serial 12345, classic, star, band dots → `8fc7c9f4fcdb32c0`.
- Editor: no raw hex/px/rem/em in `.ts/.tsx/.css` (only `var(--rc-*)`); the only colour literals live in `cad/catalog.json` (data). React 19, `jsx: react-jsx`, tests with vitest + testing-library. chirp checkout is read only; never write under `CHIRP_DIR`.
- Import rule for chirp modules in the editor: deep paths only (`@chirpcoop/real-chicken-ui/components`, `/wallet-pill`, `/golden-grain`, `/theme-vars`, `/dialog-focus`, `/styles.css`, `@chirpcoop/design-tokens`), never `/client` or `/index` (they drag `@chirpcoop/client-sdk` and recharts in). In chirp these become relative imports.

---

## File structure

**Part A (`cad/`)**
- `catalog.json` — schemes, icons, centre/band patterns, fees, `generator_version` (new).
- `cap_design.py` — catalog loader, `design_hash`, `validate_design` (new, no build123d import).
- `cap_marking.py` — add `PATTERNS_CENTRE`, `PATTERNS_BAND`, three new icons, `--centre/--band`, pattern checks, `--layout-json`, `--proof`, `build(..., cap=None)` (modify).
- `cap_svg.py` — sketch → SVG path helpers, layout export, proof writer (new).
- `bambu_project.py` — pure-Python Bambu 3MF plate writer + `bambu/project_settings.json` template (new).
- `cap_batch.py` — batch JSON → cached bodies → plate → manifest → proofs → slice check (new).
- `fixtures/batch_sample.json` — 3-cap fixture (new).
- `test_cap_marking.py` — parity + pattern + layout tests (modify); `test_cap_batch.py` (new).
- `slice_check.py` — accept a plate 3MF argument (modify).

**Part B (`editor/`)**
- `package.json`, `vite.config.ts`, `tsconfig.json`, `test/setup-dom.ts`, `index.html`, `src/main.tsx` (scaffold).
- `src/cap-editor/types.ts` — `CapDesign`, `CapStatus`, `Catalog`, `Layout`, `CapDesignClient`, `CapEditorCopy`.
- `src/cap-editor/design-hash.ts` (+ test) — mirrors Python.
- `src/cap-editor/cap-preview.tsx` (+ test) — pure SVG.
- `src/cap-editor/mock-client.ts` (+ test) — state machine + wallet.
- `src/cap-editor/cap-editor.tsx`, `lock-dialog.tsx`, `pickers.tsx`, `cap-editor.css` (+ tests).
- `src/cap-editor/data/catalog.json`, `data/layout.json` — copied from `cad/` by `pnpm sync:data`.
- `src/copy/hu.ts`, `src/copy/en.ts`, `src/page.tsx` — demo page with mock hens and a locale toggle.

---

### Task 1: Catalog manifest, design hash, parity test

**Files:**
- Create: `cad/catalog.json`, `cad/cap_design.py`
- Modify: `cad/test_cap_marking.py` (append a section before the tidy-up loop)

**Interfaces:**
- Produces: `load_catalog(path=None) -> dict`; `design_hash(serial:int, scheme:str, icon:str|None, centre:str|None, band:str|None) -> str`; `validate_design(cat, d: dict) -> list[str]` (empty list = valid; `d` has keys serial, scheme, icon, centre, band); `CATALOG_PATH`.

- [ ] **Step 1: Write the catalog**

```json
{
  "schema": "hen-cap-catalog/1",
  "generator_version": "dev",
  "schemes": [
    {"id": "classic", "name": {"hu": "Klasszikus", "en": "Classic"},
     "text": {"filament": "Bambu PETG Basic Black", "hex": "#101010"},
     "accent": {"filament": "Bambu PETG Basic White", "hex": "#F4F4F0"},
     "price_grain": 0},
    {"id": "meadow", "name": {"hu": "Rét", "en": "Meadow"},
     "text": {"filament": "Bambu PETG Basic Blue", "hex": "#1F5FBF"},
     "accent": {"filament": "Bambu PETG Basic White", "hex": "#F4F4F0"},
     "price_grain": 150},
    {"id": "sunset", "name": {"hu": "Naplemente", "en": "Sunset"},
     "text": {"filament": "Bambu PETG Basic Red", "hex": "#C8102E"},
     "accent": {"filament": "Bambu PETG Basic Yellow", "hex": "#F3C43E"},
     "price_grain": 300}
  ],
  "icons": [
    {"id": "heart", "name": {"hu": "Szív", "en": "Heart"}},
    {"id": "star", "name": {"hu": "Csillag", "en": "Star"}},
    {"id": "flower", "name": {"hu": "Virág", "en": "Flower"}},
    {"id": "egg", "name": {"hu": "Tojás", "en": "Egg"}},
    {"id": "sun", "name": {"hu": "Nap", "en": "Sun"}},
    {"id": "moon", "name": {"hu": "Hold", "en": "Moon"}}
  ],
  "centre_patterns": [
    {"id": "rings", "name": {"hu": "Körök", "en": "Rings"}},
    {"id": "solid", "name": {"hu": "Tele", "en": "Solid"}},
    {"id": "dots", "name": {"hu": "Pöttyök", "en": "Dots"}}
  ],
  "band_patterns": [
    {"id": "stripes", "name": {"hu": "Csíkok", "en": "Stripes"}},
    {"id": "dots", "name": {"hu": "Pöttyök", "en": "Dots"}},
    {"id": "arc", "name": {"hu": "Ív", "en": "Arc"}}
  ],
  "fees": {"reedit_grain": 50, "replacement_grain": 500}
}
```

`generator_version` stays `"dev"` in git; the batch CLI compares it to the batch file. Prices and fees are placeholders (spec §12).

- [ ] **Step 2: Write `cad/cap_design.py`**

```python
# /// script
# requires-python = ">=3.11,<3.13"
# dependencies = []
# ///
"""Catalog and design identity shared by the generator, the batch CLI and the
tests. Deliberately free of build123d so it imports in milliseconds."""

import hashlib
import json
from pathlib import Path

CATALOG_PATH = Path(__file__).parent / "catalog.json"
HASH_VERSION = 1

def load_catalog(path: Path | None = None) -> dict:
    cat = json.loads((path or CATALOG_PATH).read_text())
    if cat.get("schema") != "hen-cap-catalog/1":
        raise SystemExit(f"unsupported catalog schema {cat.get('schema')!r}")
    return cat

def ids(cat: dict, key: str) -> list[str]:
    return [e["id"] for e in cat[key]]

def design_hash(serial: int, scheme: str, icon: str | None,
                centre: str | None, band: str | None) -> str:
    canon = json.dumps({"band": band, "centre": centre, "icon": icon,
                        "scheme": scheme, "serial": serial, "v": HASH_VERSION},
                       sort_keys=True, separators=(",", ":"))
    return hashlib.sha256(canon.encode()).hexdigest()[:16]

def validate_design(cat: dict, d: dict) -> list[str]:
    """Every problem with one design, as human-readable strings."""
    errs = []
    serial = d.get("serial")
    if not isinstance(serial, int) or isinstance(serial, bool) or not 1 <= serial <= 99999:
        errs.append("serial must be an integer 1..99999")
    if d.get("scheme") not in ids(cat, "schemes"):
        errs.append(f"unknown scheme {d.get('scheme')!r}")
    icon, centre, band = d.get("icon"), d.get("centre"), d.get("band")
    if icon is not None and icon not in ids(cat, "icons"):
        errs.append(f"unknown icon {icon!r}")
    if centre is not None and centre not in ids(cat, "centre_patterns"):
        errs.append(f"unknown centre pattern {centre!r}")
    if band is not None and band not in ids(cat, "band_patterns"):
        errs.append(f"unknown band pattern {band!r}")
    if icon is not None and centre is not None:
        errs.append("icon and centre pattern are mutually exclusive")
    if not errs and "design_hash" in d:
        want = design_hash(serial, d["scheme"], icon, centre, band)
        if d["design_hash"] != want:
            errs.append(f"design_hash {d['design_hash']} does not match fields ({want})")
    return errs
```

- [ ] **Step 3: Append the parity/hash test section to `test_cap_marking.py`** (before the `# Tidy the per-test artifacts` block)

```python
print("=== catalog parity and design hash ===")
sys.path.insert(0, str(HERE))
from cap_design import design_hash, load_catalog, validate_design  # noqa: E402
import cap_marking as cm  # noqa: E402
cat = load_catalog()
check(sorted(e["id"] for e in cat["icons"]) == sorted(k for k in cm.ICONS if k != "none"),
      "catalog icons == generator ICONS")
check(sorted(e["id"] for e in cat["centre_patterns"]) == sorted(cm.PATTERNS_CENTRE),
      "catalog centre patterns == PATTERNS_CENTRE")
check(sorted(e["id"] for e in cat["band_patterns"]) == sorted(cm.PATTERNS_BAND),
      "catalog band patterns == PATTERNS_BAND")
check(design_hash(67, "classic", "heart", None, "stripes") == "05dcdb796b921b25",
      "design_hash test vector 1")
check(design_hash(8, "meadow", None, "rings", None) == "0371884d05cc4f6b",
      "design_hash test vector 2")
check(validate_design(cat, {"serial": 67, "scheme": "classic", "icon": "heart",
                            "centre": "rings", "band": None})
      == ["icon and centre pattern are mutually exclusive"], "icon+centre rejected")
check(validate_design(cat, {"serial": 0, "scheme": "nope", "icon": None, "centre": None,
                            "band": None})[:2]
      == ["serial must be an integer 1..99999", "unknown scheme 'nope'"], "serial/scheme rejected")
```

Importing `cap_marking` at test time loads build123d (~2 s); acceptable.

- [ ] **Step 4: Run the suite; expect the two pattern-parity checks to FAIL** (`PATTERNS_CENTRE` does not exist yet) and the icon parity to FAIL (egg/sun/moon missing)

Run: `cd cad && dev-budget run --kind heavy -- uv run --python 3.12 test_cap_marking.py`
Expected: `AttributeError: module 'cap_marking' has no attribute 'PATTERNS_CENTRE'` (a crash, not a check) — that is the red state for Task 2.

- [ ] **Step 5: Commit**

```bash
git add cad/catalog.json cad/cap_design.py cad/test_cap_marking.py
git commit -m "feat(cad): catalog manifest, design hash, parity test"
```

---

### Task 2: Patterns, new icons and their checks in the generator

**Files:**
- Modify: `cad/cap_marking.py` (icons block ~line 270–301, `build_lettering`, `build`, `main` argparse + checks)
- Modify: `cad/test_cap_marking.py` (matrix + rejections)

**Interfaces:**
- Produces: `PATTERNS_CENTRE: dict[str, Callable[[], bd.Sketch]]`, `PATTERNS_BAND: dict[str, Callable[[], bd.Sketch]]`, `ICONS` gains `egg`, `sun`, `moon`; `BAND_WINDOW = (-10.0, 190.0)`; `build_lettering(number, top, icon, centre=None, band=None) -> (mk, ic, spans, stroke_raw, band_sk)`; `build(number, top, icon, depth, centre=None, band=None, cap=None) -> (cap, shell, inlay, core_body, mk, core, spans, stroke_raw, band_sk)`; CLI flags `--centre {rings,solid,dots}`, `--band {stripes,dots,arc}`.

- [ ] **Step 1: Add the icon and pattern sketches** (after `flower_sketch`)

```python
def egg_sketch(h: float = 12.0) -> bd.Sketch:
    """Egg: a circle stretched 1.3x along Y, tip up."""
    return bd.Sketch() + bd.Ellipse(h / 2 / 1.3, h / 2)

def sun_sketch(r: float = 6.9) -> bd.Sketch:
    """Disc plus eight 1.1 mm rays; rays overlap the disc so it is one face."""
    out = bd.Circle(r * 0.5)
    for k in range(8):
        a = 45 * k
        out = out + bd.Rot(0, 0, a) * bd.Pos(r * 0.62, 0) * bd.Rectangle(r * 0.76, 1.1)
    return out

def moon_sketch(r: float = 6.6) -> bd.Sketch:
    """Crescent: a disc minus an offset disc, horns to the left."""
    return bd.Circle(r) - bd.Pos(r * 0.45, 0) * bd.Circle(r * 0.82)

ICONS = {"heart": heart_sketch, "star": star_sketch, "flower": flower_sketch,
         "egg": egg_sketch, "sun": sun_sketch, "moon": moon_sketch, "none": None}

# --- patterns ---------------------------------------------------------------
# Centre patterns replace the icon inside the accent disc (text colour);
# band patterns sit in the lettering band above the number (accent colour).
# Every element >= 0.8 mm, every gap >= 0.8 mm: printable with a 0.4 nozzle.
CORE_PATTERN_R_MAX = 7.4     # keeps >= 1.2 mm of accent ring outside
BAND_PATTERN_R = (12.2, 14.8)
BAND_WINDOW = (-10.0, 190.0)  # deg; clear of a 5-digit number by 22 deg each side
PATTERN_FEATURE_MIN = 0.8
PATTERN_GAP_MIN = 0.8

def rings_sketch() -> bd.Sketch:
    out = bd.Sketch()
    for r_in in (1.6, 4.0, 6.4):
        out = out + (bd.Circle(r_in + 0.9) - bd.Circle(r_in))
    return out

def solid_sketch() -> bd.Sketch:
    return bd.Sketch() + bd.Circle(7.3)

def centre_dots_sketch() -> bd.Sketch:
    out = bd.Circle(1.0)
    for k in range(8):
        a = math.radians(45 * k)
        out = out + bd.Pos(5.2 * math.cos(a), 5.2 * math.sin(a)) * bd.Circle(0.9)
    return out

def _annular_sector(r_in: float, r_out: float, a0: float, a1: float) -> bd.Sketch:
    n = max(2, int((a1 - a0) / 5) + 1)
    pts = [(0.0, 0.0)] + [
        ((r_out + 2) * math.cos(math.radians(a0 + (a1 - a0) * i / n)),
         (r_out + 2) * math.sin(math.radians(a0 + (a1 - a0) * i / n)))
        for i in range(n + 1)]
    return (bd.Circle(r_out) - bd.Circle(r_in)) & bd.Polygon(*pts, align=None)

def stripes_sketch() -> bd.Sketch:
    r_in, r_out = BAND_PATTERN_R
    out = bd.Sketch()
    for a in range(-6, 187, 12):
        out = out + bd.Rot(0, 0, a) * bd.Pos((r_in + r_out) / 2, 0) * bd.Rectangle(r_out - r_in, 0.9)
    return out

def band_dots_sketch() -> bd.Sketch:
    out = bd.Sketch()
    for a in range(-5, 186, 10):
        out = out + bd.Pos(13.5 * math.cos(math.radians(a)), 13.5 * math.sin(math.radians(a))) * bd.Circle(0.6)
    return out

def arc_sketch() -> bd.Sketch:
    return _annular_sector(13.05, 13.95, BAND_WINDOW[0], BAND_WINDOW[1])

PATTERNS_CENTRE = {"rings": rings_sketch, "solid": solid_sketch, "dots": centre_dots_sketch}
PATTERNS_BAND = {"stripes": stripes_sketch, "dots": band_dots_sketch, "arc": arc_sketch}

def pattern_gap_ok(sk: bd.Sketch) -> bool:
    """Islands closer than PATTERN_GAP_MIN merge when each is dilated by half
    of it, so a changed face count means a gap too narrow to print."""
    return len(fatten(sk, PATTERN_GAP_MIN / 2).faces()) == len(sk.faces())

def led_ring_clear_fraction(*inlays: bd.Sketch) -> float:
    ring = bd.Circle(11.5) - bd.Circle(8.5)
    covered = 0.0
    for sk in inlays:
        hit = ring & sk
        covered += hit.area if hit is not None else 0.0
    return 1.0 - covered / ring.area
```

- [ ] **Step 2: Extend `build_lettering` and `build`**

Replace the icon block at the end of `build_lettering` and its signature:

```python
def build_lettering(number: str, top: str, icon: str, centre: str | None = None,
                    band: str | None = None):
    ...  # unchanged number/top code above
    ic = None
    if centre is not None:
        ic = PATTERNS_CENTRE[centre]()
    elif ICONS[icon] is not None:
        ic = ICONS[icon]()
    if ic is not None:
        if radial_range(ic)[1] > CORE_R_OUT - 1.2:
            raise SystemExit(f"centre element too large for the accent disc")
        mk = mk + ic
    band_sk = PATTERNS_BAND[band]() if band is not None else None
    if band_sk is not None:
        # keep the accent-colour band pattern away from the text-colour number
        lo_w, hi_w = BAND_WINDOW
        gap = min((b_lo - hi_w) % 360, (lo_w - b_hi) % 360)
        if gap < GAP_ARC / 2:
            raise SystemExit(f"band pattern within {gap:.0f} deg of the number")
    return mk, ic, spans, stroke_raw, band_sk
```

and in `build`:

```python
def build(number: str, top: str, icon: str, depth: float, centre: str | None = None,
          band: str | None = None, cap: bd.Solid | None = None):
    p = P
    z_top = p.z_ceiling + p.cap_top_t
    mk, ic, spans, stroke_raw, band_sk = build_lettering(number, top, icon, centre, band)
    core = bd.Circle(CORE_R_OUT) - ic if ic is not None else bd.Circle(CORE_R_OUT)
    if band_sk is not None:
        core = core + band_sk          # same filament (accent), one body
    if cap is None:
        cap = build_cap(p, foam=FOAM_INNER)
    inlay = bd.Pos(0, 0, z_top - depth) * bd.extrude(mk, amount=depth)
    shell = cap - inlay
    core_body = bd.Pos(0, 0, z_top - depth) * bd.extrude(core, amount=depth)
    shell = shell - core_body
    return cap, shell, inlay, core_body, mk, core, spans, stroke_raw, band_sk
```

- [ ] **Step 3: CLI flags and checks in `main`**

Add after `--icon`:

```python
    ap.add_argument("--centre", default=None, choices=sorted(PATTERNS_CENTRE),
                    help="centre pattern instead of an icon")
    ap.add_argument("--band", default=None, choices=sorted(PATTERNS_BAND),
                    help="pattern in the band above the number (accent colour)")
```

After parsing: `if a.centre is not None and a.icon != "none" and "--icon" in sys.argv: raise SystemExit("--centre and --icon are mutually exclusive")`; pass `a.centre, a.band` into `build(...)` and unpack the extra `band_sk`. Add checks after "icon fills its cut in the disc":

```python
    for label, sk in (("centre pattern", ic if a.centre else None), ("band pattern", band_sk)):
        if sk is None:
            continue
        check(min_feature(sk) >= PATTERN_FEATURE_MIN, f"{label} feature printable",
              f"{min_feature(sk):.2f} mm >= {PATTERN_FEATURE_MIN}")
        check(pattern_gap_ok(sk), f"{label} gaps printable",
              f">= {PATTERN_GAP_MIN} mm between islands")
    clear = led_ring_clear_fraction(mk, core)
    check(clear >= 0.60, "LED ring stays clear", f"{clear * 100:.0f}% of r 8.5-11.5 open")
```

- [ ] **Step 4: Tests** — extend the acceptance matrix in `test_cap_marking.py`:

```python
    ("67",    ["--centre", "rings", "--band", "stripes"]),
    ("99999", ["--icon", "sun", "--band", "dots"]),
    ("3",     ["--centre", "solid", "--band", "arc"]),
    ("4242",  ["--centre", "dots", "--icon", "none"]),
```

and rejections: `("icon and centre together", ["7", "--icon", "star", "--centre", "rings"], "mutually exclusive")`, `("unknown band", ["7", "--band", "zigzag"], "invalid choice")`.

- [ ] **Step 5: Run the suite**

Run: `cd cad && dev-budget run --kind heavy -- uv run --python 3.12 test_cap_marking.py`
Expected: all PASS including the Task 1 parity checks (icons now 6; the "LED ring stays clear" check ≥ 60 % for every matrix row; fix radii if one fails — the numbers above were chosen with margin).

- [ ] **Step 6: Commit**

```bash
git add cad/cap_marking.py cad/test_cap_marking.py
git commit -m "feat(cad): centre and band patterns, egg/sun/moon icons, printability checks"
```

---

### Task 3: Layout export and proof SVG

**Files:**
- Create: `cad/cap_svg.py`
- Modify: `cad/cap_marking.py` (`main`: `--layout-json`, `--proof`)
- Modify: `cad/test_cap_marking.py`

**Interfaces:**
- Produces: `sketch_to_path(sk: bd.Sketch, samples: int = 16) -> str` (SVG `d`, mm, y-up, evenodd subpaths); `digit_outlines() -> dict[str, dict]` (`{"0": {"d": ..., "advance": 3.814}}`, glyph bbox centred at origin); `write_layout(path: Path) -> dict`; `write_proof(path: Path, mk, core, scheme: dict) -> None`.
- Layout JSON schema `hen-cap-layout/1`:

```json
{"schema":"hen-cap-layout/1","generator_version":"dev",
 "cap_r":15.97,"scallops":{"n":8,"r":1.4,"orbit":17.12},
 "core_r":8.6,"band":{"r_min":9.6,"r_max":15.4},"band_window":[-10,190],
 "number":{"font_pt":6.0,"centre_deg":270,"base_r":12.5,"stroke":0.36,
           "advance":3.814,"digits":{"0":"M ... Z", "...":"..."}},
 "icons":{"heart":"M ... Z"},"centre_patterns":{"rings":"..."},"band_patterns":{"stripes":"..."}}
```

- [ ] **Step 1: Write `cad/cap_svg.py`**

```python
# /// script
# requires-python = ">=3.11,<3.13"
# dependencies = ["build123d"]
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

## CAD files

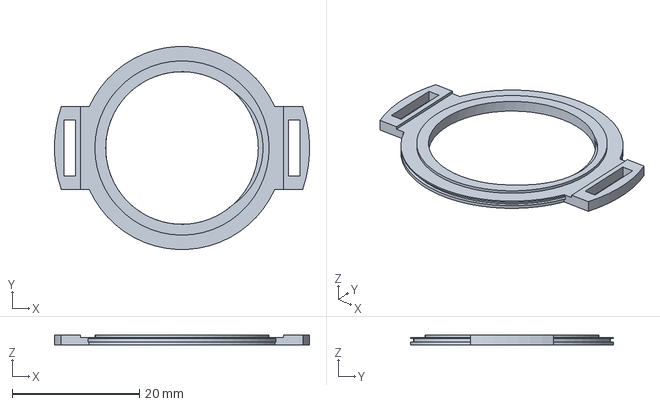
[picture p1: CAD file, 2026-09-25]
cad/out/coupon_flangering.step
40.1 x 31.9 x 1.60 mm

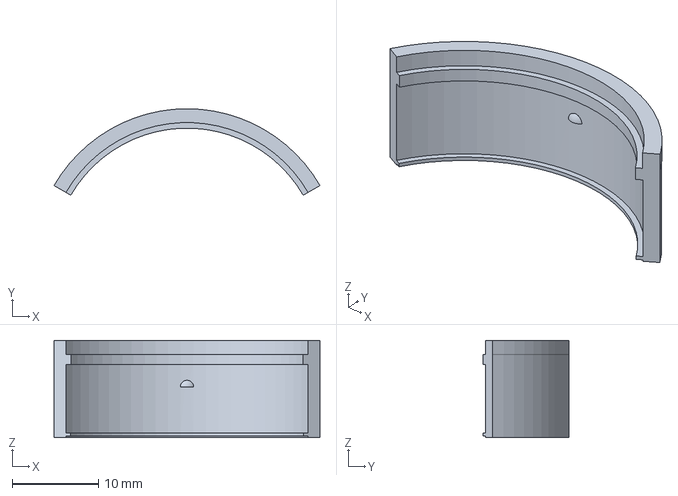
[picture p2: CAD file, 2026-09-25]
cad/out/coupon_collar.step
30.8 x 10.0 x 11.2 mm

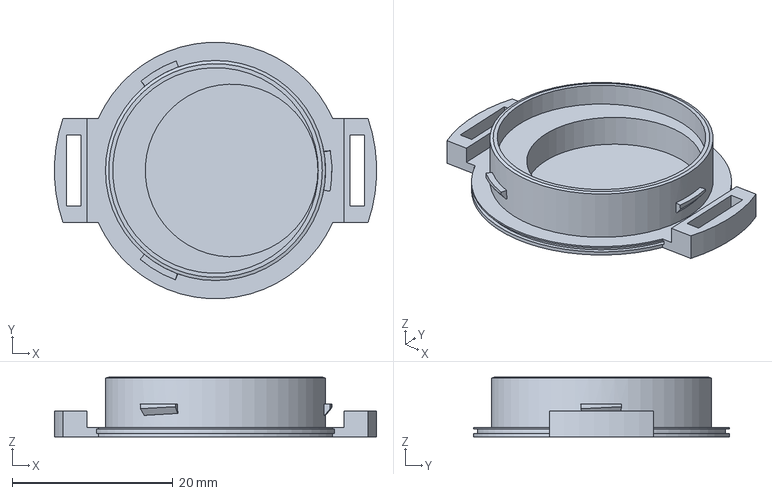
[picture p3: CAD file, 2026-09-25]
cad/out/body_platform.step
40.1 x 31.9 x 7.45 mm

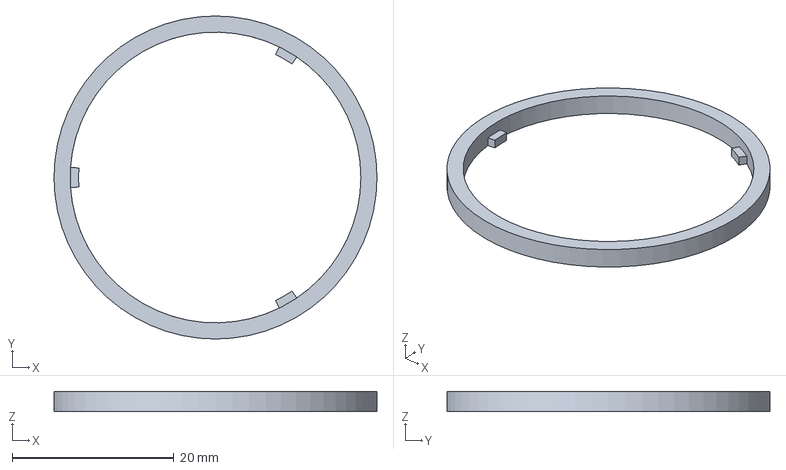
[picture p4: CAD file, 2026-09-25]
cad/out/halo_accessory.step
40.0 x 40.0 x 2.50 mm

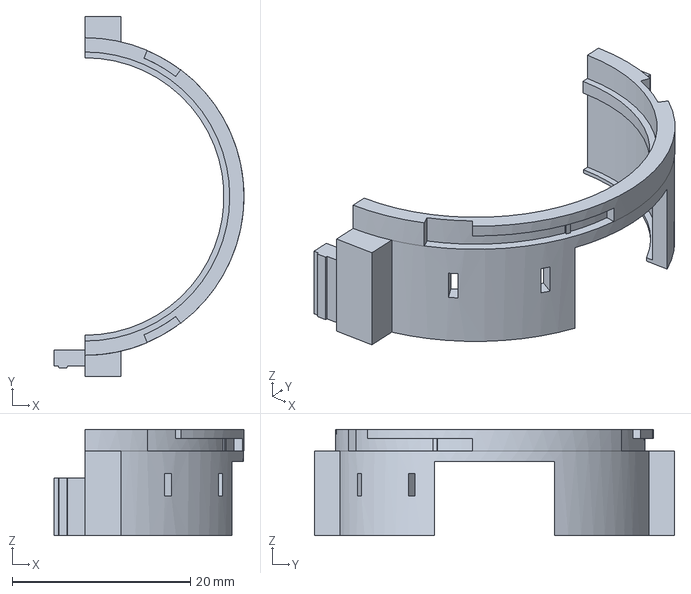
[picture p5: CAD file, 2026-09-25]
cad/out/collar_half_b.step
21.3 x 40.4 x 11.9 mm

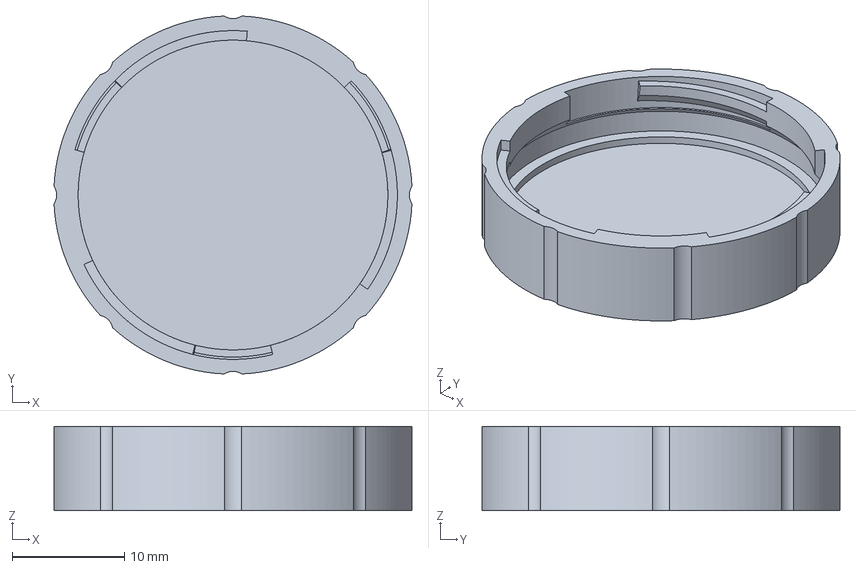
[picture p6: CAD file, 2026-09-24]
cad/out/cap_67_P1S.3mf
31.9 x 31.9 x 7.50 mm

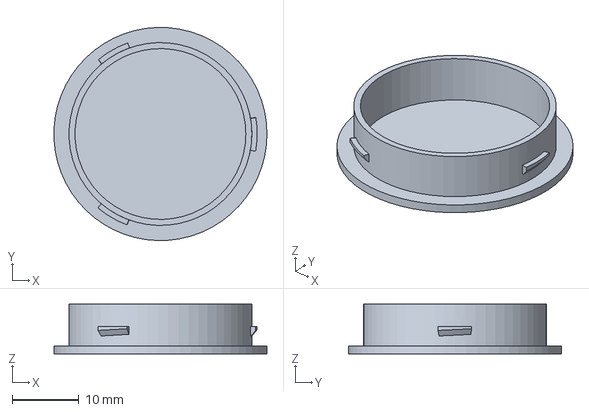
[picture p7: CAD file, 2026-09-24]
cad/out/coupon_body.step
31.9 x 31.9 x 7.45 mm

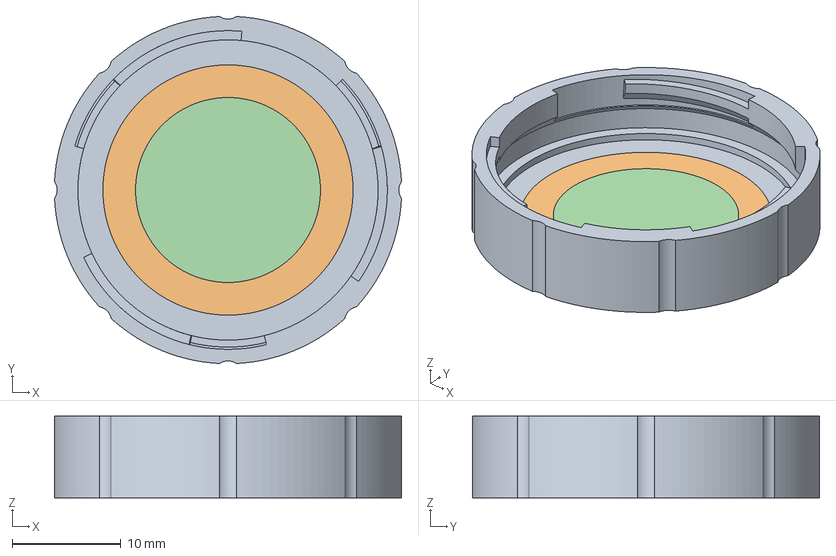
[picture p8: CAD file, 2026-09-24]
cad/out/cap_67.3mf
31.9 x 31.9 x 7.50 mm
cap_67
window_67
a_67
b_67

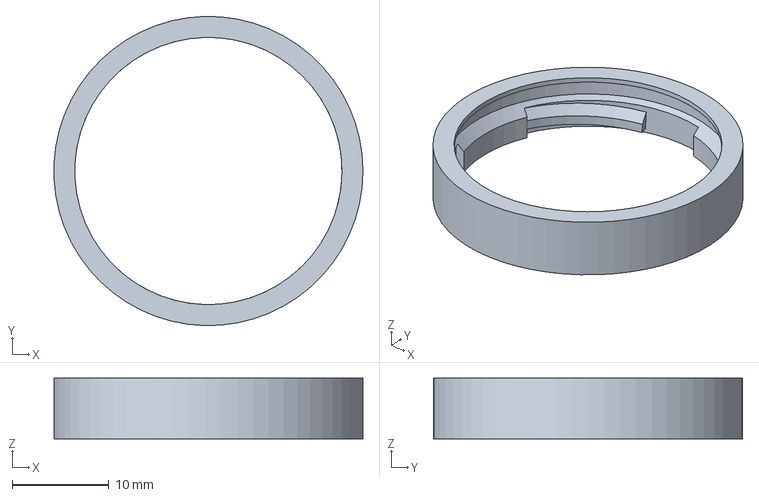
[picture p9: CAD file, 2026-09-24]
cad/out/coupon_cap.step
31.9 x 31.9 x 6.25 mm

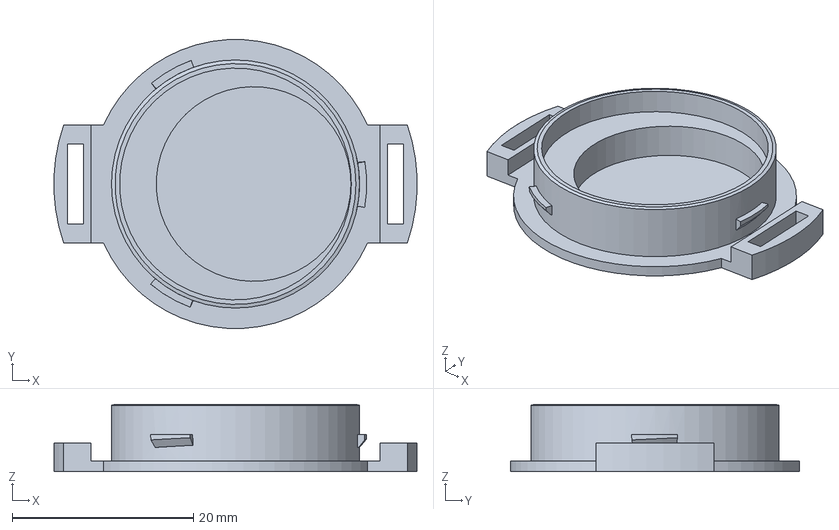
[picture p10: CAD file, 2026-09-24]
cad/out/body.step
40.1 x 31.9 x 7.45 mm

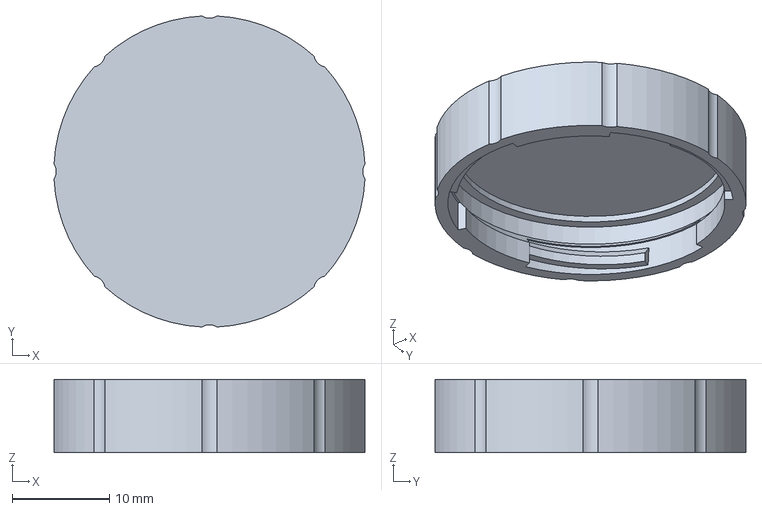
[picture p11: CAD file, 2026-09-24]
cad/out/cap.step
31.9 x 31.9 x 7.50 mm

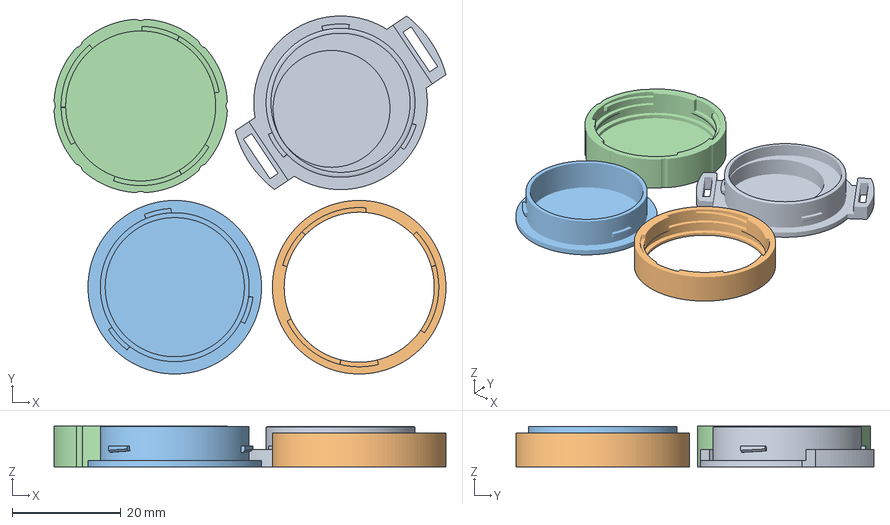
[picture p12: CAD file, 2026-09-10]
cad/out/hen_tag_revC_P1S.3mf
72.1 x 65.9 x 7.50 mm
body.stl
coupon_cap.stl
coupon_body.stl
cap.stl

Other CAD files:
cad/out/collar_half_a.step
cad/out/body.stl
cad/out/body_platform.stl
cad/out/cap.stl
cad/out/collar_half_a.stl
cad/out/collar_half_b.stl
cad/out/coupon_body.stl
cad/out/coupon_cap.stl
cad/out/coupon_collar.stl
cad/out/coupon_flangering.stl
cad/out/halo_accessory.stl

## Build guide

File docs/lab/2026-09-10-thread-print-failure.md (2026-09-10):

# Lab Note: Thread Print Failure; Bayonet Closure Adopted (Revision C)

- **Date**: 2026-09-10
- **Author**: Hen-Tag Engineering
- **Status**: Completed (root cause) / Bayonet coupon printed once —
  dimensions good, lock-up angle unreported (print trial 1 below)

---

## Purpose & Objective

Record the operator's report that the cap and its screw thread do not print
cleanly, find the geometric cause, and replace the closure with one whose
every face prints on a 0.4 mm nozzle without support, on both parts, in
their real print orientations.

---

## Reported / Measured

- **Operator, 2026-09-10**: the cap and the screw thread "cannot be printed
  nicely — lots of tearing, too steep." Printer and filament not stated
  beyond the standing transparent-PETG profile (Bambu Lab P1S, 0.4 mm,
  0.16 mm layers).
- This contradicts the 2026-08-28 revision A note, where one printed pair
  was reported to mate without binding. That was a single pair; the caps
  printed since are the three-body clear-shell caps from `cap_marking.py`,
  which carry the same thread.

---

## Technical Interpretation

Computed from the revision B `Params` (Tr28.6 × 1.0, 30° included angle,
0.55 mm deep, `fit_thread_a` 0.15 per flank):

| Feature | Value | Why it tears |
|---|---|---|
| Flank angle from horizontal | 15° | A 75° overhang. Every ridge is a 0.55 mm shelf about three layers tall. |
| Male (body) crest width | 0.35 mm | Below one 0.40 mm extrusion. |
| Female (cap) crest width | **0.05 mm** | (1.0 − 0.647) − 2 × 0.15. A knife edge, two layers tall. |
| Female ridge root width | 0.35 mm | The whole ridge is thinner than one extrusion at its base. |

The cap prints top-plate-down, so its internal ridge is a knife edge hanging
from a 75° overhang. Tearing along the thread is the expected outcome of
this geometry, not a printer fault; the revision A pair mating was one good
print, not evidence the profile is robust. `verify.py`'s overhang check did
not catch it because its limits were calibrated to that same revision A
print.

---

## Key Decisions

1. **The thread is replaced by a three-lug bayonet (revision C).** Lugs on
   the body's seal band (20° × 0.80 mm proud, z 1.80–2.80); L-channels in the
   cap skirt with an entry slot at the open end and a helical lip under the
   circumferential leg. The cap turns **30° clockwise** to lock; the lips
   rise 12 µm per degree (2.7° helix angle, self-locking) and wedge the skirt
   onto the base flange exactly where the thread used to stop it.
2. **Printability rule that sized every number**: on both parts, in print
   orientation, the only flat overhang is the 0.50 mm bearing flat (one
   extrusion width); everything outboard of it is chamfered at 50°. Lugs
   stand on the band, lips hang from the skirt.
3. **Lug and lip bearing faces share one helix pitch**, so at lock they meet
   flat on flat (5.8 mm² over three lugs) rather than edge on face.
4. **Nothing else moved.** Radial seal and groove, cap OD 31.94 mm, grip
   scallops, tabs, lettering, LED ring, the accessory-platform interface and
   the assembly rule "closure below the seal" are unchanged. `cap_marking.py`
   and `hen_tag_platform.py` inherit the new skirt untouched.
5. **Thread code removed** from the source, along with the `bd_warehouse`
   dependency. Commit `e3cf940` has the revision B thread if it is ever
   needed for comparison.

---

## Verification (model only)

`cad/verify.py`, 38 checks, all passing, of which the closure-specific ones:

- cap drops on at the entry angle and the lugs run free for 0–28°:
  0.000 mm³ overlap at every step
- ramp wedges past the lock angle: 0.296 mm³ interference at +4°
- locked cap retained: 5.77 mm³ lug/lip overlap when lifted 0.6 mm; lifts
  off clean at the entry angle
- print-error window the ramp absorbs: −0.36 … +0.30 mm axial; the locked
  angle moves 4.2° per 0.05 mm of error (the thread moved 18°)
- lip 1.41 mm thick at its thin end (8.8 layers)
- worst unsupported overhang band: body 9.36 → **3.03 mm²**, cap total
  242 → 115 mm² (the remaining 96 mm² band is the O-ring groove ceiling,
  unchanged since revision A)

The COMMON and CUT booleans were cross-checked at every pose and agree to
0.001 mm³. OCCT mis-fuses the two helical solids in the *lifted entry* pose
(a 277 mm³ union), so the `section_entry` inspection STL is built as a
compound; the fit checks do not use the fuse. `test_cap_marking.py`: 28/28;
platform coupons: 0.000 mm³ interference against the new body and cap.

---

## Open Questions & Verification Items

1. **Print the coupon pair** (`coupon_body.stl`, `coupon_cap.stl`) and
   record: does the cap drop on with the entry slots over the lugs; at what
   angle does it stop turning freely (nominal 30°, usable 5–55°); break-loose
   torque by feel; O-ring groove profile. The lock-up angle re-tunes
   `cam_lock`; a radial bind re-tunes `fit_lug_r`. Do not file the parts.
2. **Peck/snag resistance.** A bayonet opens with a 30° turn where the
   thread needed several. The platform collar's spring finger was already
   the intended deployment lock; bench a printed cap for break-loose torque
   before any flock trial.
3. **Remaining cap overhang** is the O-ring groove ceiling (1.07 mm wide,
   96 mm² band). It printed on revision A. If tearing persists there, a
   0.4 mm chamfer on the groove's outer corner removes 40 % of it without
   the ring ever touching the chamfer.
4. ~~Revision C has not been sliced yet.~~ Sliced 2026-09-10, no warnings on
   any part; see print trial 1 below.

---

## Print Trial 1 — coupon pair, same day

- **Operator, 2026-09-10 (photo)**: the bayonet coupon pair printed in red
  PETG. **Dimensions reported good.** The cap coupon came off the plate with
  a web of fine strands across its bore, converging near the centre.

### Technical Interpretation

Not a geometry defect: the strands are PETG ooze left on **travel moves**
that fly across the open bore. The G-code was read back to count them
(`cad/slice_check.py`; a travel counts when it is longer than 3 mm and
passes within 12 mm of the axis, above the top plate):

| Part | Stock Bambu profile (2 walls, classic, no travel routing) | 3 walls, Arachne, *Avoid crossing walls* |
|---|---|---|
| `coupon_cap` | **58** travels, 1.4 m | **3** travels, 81 mm |
| `cap` | 107 travels, 2.5 m | 19 travels, 0.4 m |
| `coupon_body` (bore) | 96 travels, 2.1 m | 0 |
| `body` (across the cell pocket) | 102 travels, 2.1 m | 68 travels, 0.8 m |
| `body` (cavity above the fill) | 1 | 0 |

Why the bayonet invites it: in every layer of the lip zone the skirt's
cross-section is a 1.32 mm wall with three 2.17 mm-thick arcs (the lips and
the plain skirt between them), separated by the three entry slots. Three
walls fill the thin part; the extra width of each arc needs its own line, so
the slicer prints three separate islands per layer and hops between them —
straight across the bore unless told to route around. The revision B thread
had the same issue in a different shape (the helical ridge is one arc per
layer): sliced the same way it gave **106** crossing travels on the cap
against revision C's 112, so the strands are not new, only more visible on an
open coupon ring. With travel routing on, the residual 3–19 are layer-change
hops (the nozzle lifts, then travels straight), inside the cap, and pull off
by hand.

No slicer warning was raised for any revision C part with either profile.
The slicer's `max_cantilever_dist` is 0 for the body and body coupon (as on
revisions A and B) and 64 966 for the cap and cap coupon — the revision B cap
measured 64 968, so that figure is the O-ring groove ceiling and the lips add
nothing to it.

### Key Decisions

1. **Three process settings become part of the print profile** and are
   recorded in `DESIGN.md` and `README.md`: wall loops **3**, wall generator
   **Arachne**, **Avoid crossing walls ON**. Nothing in the geometry changes.
2. **`cad/slice_check.py` added**: slices the four printables through the
   Bambu Studio CLI with those settings and fails when open-air travels
   exceed limits set just above today's numbers, or when the slicer warns.
   `--stock` shows the untouched profile for comparison. Skips when Bambu
   Studio is not installed.

### Open Questions & Verification Items

1. Reprint the coupon pair with the three settings and confirm the bore is
   clean; the remaining hairs should be at layer changes only.
2. **Lock-up angle still unreported** — the drop-on and the angle at which
   the cap stops turning freely are the numbers that tune `cam_lock`.
3. If the cell-pocket travels on the full body leave hairs on the cell
   holder, lower the lugs (`lug_z`) to shorten the lip zone, or accept and
   clean; the pocket is closed by the cell in service.

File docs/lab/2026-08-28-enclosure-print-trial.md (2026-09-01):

# Lab Note: Enclosure Print Trial, Revision A

- **Date**: 2026-08-28
- **Author**: Hen-Tag Engineering
- **Status**: Completed / Fit confirmed on printed parts

---

## Purpose & Objective

First physical print of the generated enclosure geometry, to confirm that the
modelled thread clearances and cavity dimensions survive contact with a real
FDM machine before committing to a revision.

---

## Verified Evidence

- **Printer**: Bambu Lab P1S.
- **Parts printed**: revision A body and cap as exported from
  `cad/hen_tag_enclosure.py`.
- **Result — dimensions**: reported good by the operator. The Ø25 board cavity
  and the 6.0 mm stack height accepted the hardware as modelled.
- **Result — thread**: reported good. The Tr28.6 × 1.0 trapezoidal pair with
  `fit_thread_r = 0.25` / `fit_thread_a = 0.15` mates on printed parts without
  binding or excessive play.

This is the first entry in this repository where enclosure geometry moves from
modelled to physically confirmed. It validates the print-process parameters —
clearances, wall thicknesses, thread profile — not the board dimensions those
parts were sized around, which remain unverified caliper readings.

---

## Technical Interpretation & Findings

1. **The thread clearance figures are now empirical, not assumed.** The values
   in `Params` can be treated as a known-good baseline for this printer and
   should not be changed without a fresh coupon print.
2. **The trapezoidal profile choice is validated for FDM.** A 30° included
   angle at 1.0 mm pitch prints and mates on a 0.4 mm nozzle.
3. **No dimensional correction was required** between the modelled and printed
   parts, so no printer-specific compensation factor is needed in the source.

---

## Key Decisions

Revision B, driven by the operator after handling the printed parts:

1. **Board orientation inverted.** The holder now faces down toward the harness
   and the PCB faces up, away from the bird, so the LED on the PCB is visible
   through the transparent cap. Previously the PCB faced down and the LED was
   pointed at the animal.
2. **Fill added around the cell.** The crescent of cavity the offset holder
   does not occupy is filled to just below the PCB face, so the enclosure body
   itself retains the holder rather than relying on the cavity wall alone.
3. **Harness moved from under-floor bridges to in-plane side tabs.** The
   underside is now completely flat; each tab carries a transverse slot and a
   bar the elastic wraps. Assembled height drops from 11.50 mm to 8.70 mm.

---

---

## Follow-up: Slicer-Reported Defect in Revision B

Bambu Studio rejected the first revision B body with *"It seems object body.stl
has floating cantilever. Please re-orient the object or enable support
generation."*

**Root cause, confirmed:** the rim's lead-in chamfer was cut with a cone tapering
the wrong way. It thinned the wall to a 0.10 mm knife edge low down and left a
downward-facing annular shelf above it. Mesh analysis located it as ~73 mm² of
near-horizontal down-facing area at z 5.8–5.9.

Verified by slicing both versions of the same part:

| Version | `max_cantilever_dist` | Result |
|---|---|---|
| Inverted chamfer | 1.37 × 10⁶ | floating-cantilever warning |
| Corrected chamfer | 0 | `Success.`, no warnings |

Two further printability items were found and fixed in the same pass:

1. **Thread started 0.2 mm above the base flange**, leaving its first ridge
   floating. Now flush; the body's worst overhang band fell from 18.95 mm² to
   9.36 mm².
2. **The cap exported in design orientation** would have landed opening-down on
   the plate, turning its top plate into a ~28 mm bridge over the cavity. STLs
   are now exported already lying in their print orientation.

All four parts now slice with `Success.` and zero warnings on Bambu Studio
02.08.02.60 at default settings.

---

## Open Questions & Verification Items

1. **Revision B has not been printed.** The fill, the tabs and the inverted
   stack are modelled and machine-checked but physically untested. In
   particular the tab root, which is only as thick as the base flange, has not
   been load-tested with an elastic.
2. **LED visibility through the cap is unconfirmed.** The foam ring leaves a
   Ø16 mm window, but the LED position on the PCB is still unknown, so it is
   not proven that the LED falls inside that window rather than under the ring.
3. **Mass**: revision B models at 10.89 g against the ~10 g target, up from
   10.19 g, because the cell fill adds about 0.7 g. Still unweighed.
4. **Ingress**: no water or dust test has been performed on any revision.

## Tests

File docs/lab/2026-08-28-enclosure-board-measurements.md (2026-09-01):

# Lab Note: Holyiot 25008 Board Measurements for Enclosure CAD

- **Date**: 2026-08-28
- **Author**: Hen-Tag Engineering
- **Status**: Partial / Caliper readings reported, not independently re-measured

---

## Purpose & Objective

Capture the physical board dimensions needed to unblock enclosure CAD, which
`docs/requirements.md` had listed as pending since repository scaffolding.

---

## Reported Measurements

Reported by the operator from caliper readings on the bench board. These have
**not** been independently re-measured or photographed, so they are recorded
here as reported values rather than as verified evidence.

| Quantity | Reported | Note |
|---|---|---|
| PCB outline | Ø25 mm, circular | Round board, not rectangular |
| PCB thickness | 2 mm | See ambiguity below |
| CR2032 holder outline | Ø21 mm | |
| CR2032 holder height | 4 mm | See ambiguity below |
| Bottom-side protrusion | not measured | Operator: "the panel is about 2 mm tall with everything" |
| Antenna location | not identifiable | "does not show, does not stick out anywhere" |

### Unresolved ambiguity in the height chain

The two height figures can be read two ways and the operator elected to proceed
without re-measuring:

- **Reading A (assumed)**: 2 mm is the full board envelope including bottom-side
  components; the 4 mm holder sits on top of it. Total stack **6.0 mm**.
- **Reading B**: 4 mm already contains the board. Total stack **4.0 mm**.

The CAD assumes **Reading A** and states the assumption in
`cad/hen_tag_enclosure.py`. A single caliper measurement of the whole
sandwich -- lowest point of the board to the top of a seated cell -- resolves
this. The design absorbs roughly +/-0.4 mm around the assumption via a foam pad,
so a wrong reading is recoverable by changing the pad, not by reprinting.

---

## Derived Geometry (verified by construction)

The holder is **internally tangent** to the PCB: the operator reports that the
two circles touch at exactly one point, and that the cell edge is flush with the
PCB edge there, which is where the cell slides in.

This is not an independent measurement but a geometric consequence that the two
reported diameters confirm:

```
centre offset = R_pcb - R_holder = 12.5 - 10.5 = 2.0 mm
```

Modelled and checked in `cad/verify.py`: edge gap at the tangent point
is 0.0000 mm, and the widest exposed PCB crescent opposite it is 4.00 mm. The
reported description and the reported diameters are therefore self-consistent.

Consequence for the enclosure: no rotationally symmetric shoulder can clamp the
board from above, because at the tangent point there is zero exposed PCB. The
design clamps the cell instead. See `DESIGN.md`.

---

## Key Decisions

- Proceed to CAD on Reading A, with every board dimension marked UNVERIFIED in
  the source and the tolerance absorbed by a replaceable foam pad.
- Do not design an antenna keep-out. The antenna could not be located, and
  inventing a zone would violate the no-invented-hardware rule. PETG is a low
  loss dielectric; the existing prohibition on conductive filament remains the
  operative RF constraint.

---

## Open Questions & Verification Items

1. **Total stack height** with a seated CR2032, measured in one span. Resolves
   Reading A vs. B.
2. **Assembly mass on a scale**: bare board, holder, and cell. The 10 g budget
   argument currently rests on two estimated figures (holder 0.6 g, O-ring
   0.4 g) and a calculated PCB mass.
3. **Elastic cross-section**: actual width and thickness of the 8 mm harness
   material. The strap channel is cut 8.6 x 2.0 mm on an assumed profile.
4. **O-ring**: actual ID and cord thickness of the ring to be used. The design
   calls for ID 26.74 x CS 1.50 mm; the previously specified 30 x 2 mm ring does
   not fit this geometry.
5. **Antenna location**, from vendor documentation or a board photograph under
   raking light.

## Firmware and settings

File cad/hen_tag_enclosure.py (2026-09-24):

# /// script
# requires-python = ">=3.11,<3.13"
# dependencies = ["build123d"]
# ///
"""Parametric enclosure for the Holyiot 25008 hen tag.

Two-part transparent PETG housing: a cup-shaped body and a bayonet cap sealed
by a radial O-ring. Run with `uv run hen_tag_enclosure.py` -- uv resolves the
dependencies above, no virtualenv setup required.

Three decisions that are not obvious from the geometry alone:

1. Radial seal, not the axial face seal in docs/requirements.md. A face seal
   must sit outboard of the cap skirt, forcing a ~36 mm flange around a 25 mm
   board; measured, that overruns the mass budget by ~1.9 g. The radial seal
   needs none.

2. Closure low, seal high. The reverse -- seal below the closure -- cannot
   assemble: the cap's internal features would have to travel past a sealing
   band of larger radius. With the closure at the bottom, the cap's channels
   only ever pass the smaller seal band, and the O-ring never crosses the lugs.

3. Bayonet, not a thread (revision C). Revisions A/B used a Tr28.6 x 1.0
   trapezoidal thread. On a 0.4 mm nozzle its ridges are sub-nozzle-width
   (the cap's ridge crest computed to 0.05 mm) and its flanks are 15 deg from
   horizontal, i.e. 75 deg overhangs -- the operator's caps tore along the
   thread. The bayonet has three 0.8 mm lugs on the body and three L-channels
   in the cap; every face on both parts, in their print orientations, is
   either steeper than 45 deg or a flat overhang of one extrusion width. A
   shallow helical ramp on the channel floor draws the cap onto the base
   flange the way the thread did, and is self-locking.

MEASUREMENT STATUS -- read before trusting any printed part:
  VERIFIED   the board and its parts: manufacturer STEP, board_holyiot_25008.py
  VERIFIED   the PCB/holder tangency (geometric consequence of 25 and 21 mm)
  UNVERIFIED the holder: user caliper readings, 2026-08-28 (the STEP's clip
             model is generic and was discarded)
  UNVERIFIED the bayonet: modelled 2026-09-10, no coupon printed yet
  UNKNOWN    antenna location, elastic cross-section, actual O-ring ID/CS

Coordinate system: Z up, millimetres. z = 0 is the cavity floor -- the surface
the PCB rests on. Angles are degrees, counter-clockwise from +X viewed from
above (the cap side); the harness tabs lie on the X axis.
"""

import math
from dataclasses import dataclass
from pathlib import Path

import build123d as bd

import board_holyiot_25008 as brd

OUT = Path(__file__).parent / "out"
PETG_DENSITY = 1.27e-3  # g/mm^3


@dataclass(frozen=True)
class Params:
    """Every dimension the design depends on, in one place."""

    # --- Board, VERIFIED from the manufacturer STEP (board_holyiot_25008) ---
    # Orientation: holder DOWN against the floor, PCB UP under the cap. The
    # LED sits on the PCB face, so it has to look outward, away from the bird.
    pcb_dia: float = brd.PCB_DIA
    pcb_t: float = brd.PCB_T     # bare board
    comp_h: float = brd.S1_H     # tallest part on the face, the centre switch
    # --- Holder, UNVERIFIED (user caliper 2026-08-28) -----------------------
    holder_dia: float = 21.0
    holder_h: float = 4.0        # holder + seated cell, off the PCB face

    # --- Print process ------------------------------------------------------
    nozzle: float = 0.4
    layer: float = 0.16
    fit_board: float = 0.30      # radial clearance, board edge to cavity wall
    body_wall: float = 0.90
    floor_t: float = 1.00
    cap_wall: float = 1.10
    cap_top_t: float = 1.10

    # --- Bayonet closure, UNVERIFIED (modelled 2026-09-10, no coupon yet) ---
    # Three lugs on the body's seal band, three L-channels in the cap skirt:
    # an axial entry slot at the skirt's open end, then a circumferential leg
    # whose floor -- the lip that carries the cap -- is a shallow helical
    # ramp. Turning the cap clockwise runs the lugs up the ramps until the
    # skirt lands on the base flange, exactly as the thread used to.
    #
    # Printability rule behind every number here: on both parts, in their
    # print orientations, NO face is flatter than chamfer_deg -- the slicer's
    # support detection (Bambu, 30 deg threshold) finds nothing to support.
    # Lug undersides and lip tops are matching 50 deg cones that bear on each
    # other. Revision C had a 0.5 mm flat bearing ledge here, and the slicer
    # put support under all three lips (2026-09-24).
    lug_n: int = 3
    lug_arc: float = 20.0        # angular width of one lug
    lug_d: float = 0.80          # radial protrusion off the seal band
    lug_h: float = 1.30          # axial height at the lug centre; the cone
                                 # takes 0.83 of it, leaving a 0.47 crest
    lug_z: float = 1.80          # underside above the cavity floor, at the centre
    chamfer_deg: float = 50.0    # lug/lip/groove cone, from horizontal (>45)
    fit_lug_r: float = 0.15      # radial clearance, lug crest to channel root
    fit_lug_z: float = 0.30      # axial clearance, lug top to channel ceiling
    fit_lug_t: float = 4.0       # angular clearance each side in the entry slot
    cam_rate: float = 0.012      # ramp rise per degree of cap rotation (mm/deg)
    cam_lock: float = 30.0       # cap rotation, entry to nominal contact
    cam_travel: float = 55.0     # lug-centre travel available before the end wall

    # --- Radial seal, UNVERIFIED (needs the actual ring measured) -----------
    oring_cs: float = 1.50
    oring_squeeze: float = 0.22  # fraction of CS compressed

    # --- Assembly -----------------------------------------------------------
    # The ceiling stays where revision A put it (holder 4.0 + the caliper's
    # 2.0 board + 0.6), because that pair closed over a real board. With the
    # STEP's 0.81 board and 1.60 switch the true head gap over S1 is 0.19.
    ceiling_h: float = 6.60
    # Foam is a RING, not a disc, and it sits inboard (r 6-8), under the
    # opaque core and clear of both the switch (r <= 2.26) and the LED
    # (r 8.78-10.91). The rim ring it replaces landed on the LED. 2.0 mm
    # because the board face is 1.79 below the ceiling; the ring bears on the
    # parts in its band (0.5-1.1 mm) and just kisses bare board.
    foam_od: float = 16.0
    foam_id: float = 12.0
    foam_t: float = 2.00
    fit_seal_r: float = 0.10     # slide clearance, cap bore over the seal band

    # --- Cell pocket --------------------------------------------------------
    fit_holder: float = 0.25     # radial clearance, holder to its pocket wall
    fill_relief: float = 0.20    # gap between the fill top and the PCB face

    # --- Harness tabs, UNVERIFIED (8 mm elastic, cross-section not measured)
    # Flat side tabs in the plane of the base, each with a transverse slot and
    # a bar at the tip. The underside of the tag stays completely flat.
    strap_w: float = 8.80        # slot length, across the spine
    strap_t: float = 1.80        # slot width, along the spine
    tab_w: float = 13.00
    tab_top: float = 2.20        # tab upper face, outboard of the cap
    tab_inner_wall: float = 0.80  # material between cap skirt and slot
    tab_bar: float = 1.50        # the bar the elastic wraps around

    # --- Board geometry -----------------------------------------------------
    @property
    def r_pcb(self) -> float:
        return self.pcb_dia / 2

    @property
    def r_holder(self) -> float:
        return self.holder_dia / 2

    @property
    def holder_offset(self) -> float:
        """Centre offset making the two circles internally tangent."""
        return self.r_pcb - self.r_holder

    @property
    def pcb_env_h(self) -> float:
        """Board plus its tallest part."""
        return self.pcb_t + self.comp_h

    @property
    def stack_h(self) -> float:
        return self.pcb_env_h + self.holder_h

    @property
    def head_gap(self) -> float:
        """Ceiling clearance over the switch, the tallest part."""
        return self.ceiling_h - self.stack_h

    @property
    def foam_gap(self) -> float:
        """Ceiling down to the bare board face under the foam ring."""
        return self.ceiling_h - self.holder_h - self.pcb_t

    # --- Radial stations ----------------------------------------------------
    @property
    def r_cav(self) -> float:
        return self.r_pcb + self.fit_board

    @property
    def r_core(self) -> float:
        """Body outer wall: the plain band the O-ring seals against."""
        return self.r_cav + self.body_wall

    @property
    def r_lug(self) -> float:
        """Lug crest."""
        return self.r_core + self.lug_d

    @property
    def r_cap_seal_bore(self) -> float:
        return self.r_core + self.fit_seal_r

    @property
    def r_cap_chan(self) -> float:
        """Root of the cap's bayonet channels."""
        return self.r_lug + self.fit_lug_r

    @property
    def r_groove_root(self) -> float:
        """Set by the squeeze target, not the other way round."""
        return self.r_core + self.oring_cs * (1 - self.oring_squeeze)

    @property
    def groove_depth(self) -> float:
        return self.r_groove_root - self.r_cap_seal_bore

    @property
    def groove_w(self) -> float:
        """Axial width at the root, where the ring sits."""
        return self.oring_cs * 1.35

    @property
    def groove_rise(self) -> float:
        """Axial run of the groove's lower cone, bore to root."""
        return self.chamfer_rise(self.r_groove_root - self.r_cap_seal_bore)

    @property
    def r_cap_out(self) -> float:
        return max(self.r_groove_root, self.r_cap_chan) + self.cap_wall

    # --- Bayonet kinematics -------------------------------------------------
    @property
    def cam_pitch(self) -> float:
        """Helix pitch (mm per turn) shared by the lugs and the lips."""
        return self.cam_rate * 360.0

    @property
    def cam_slack(self) -> float:
        """Axial play between lug and lip at the entry angle."""
        return self.cam_rate * self.cam_lock

    @property
    def cam_window(self) -> tuple[float, float]:
        """Axial print error the ramp absorbs: (tightest, loosest) still locking."""
        return (-self.cam_slack,
                self.cam_rate * (self.cam_travel - self.cam_lock))

    @property
    def entry_half(self) -> float:
        """Half-width of the entry slot, degrees."""
        return self.lug_arc / 2 + self.fit_lug_t

    @property
    def chan_end(self) -> float:
        """Angle of the channel's end wall from the entry-slot centre."""
        return self.cam_travel + self.lug_arc / 2

    def lug_angle(self, i: int) -> float:
        """Centre of lug i in the body frame; lug 0 sits on the tab axis."""
        return 360.0 * i / self.lug_n

    def chamfer_rise(self, run: float) -> float:
        return math.tan(math.radians(self.chamfer_deg)) * run

    @property
    def helix_deg(self) -> float:
        """Ramp helix angle at the lug radius; must stay below the friction angle."""
        return math.degrees(math.atan(self.cam_pitch / (2 * math.pi * self.r_lug)))

    # --- Z stations ---------------------------------------------------------
    @property
    def z_shoulder(self) -> float:
        """Top of the base flange; the cap skirt lands here."""
        return 0.20

    @property
    def z_chan_hi(self) -> float:
        """Ceiling of the cap's bayonet channels."""
        return self.lug_z + self.lug_h + self.fit_lug_z

    @property
    def z_lip_lo(self) -> float:
        """Lip top at its thin end (the entry-slot edge), cap frame."""
        return self.lug_z + self.cam_rate * (self.entry_half - self.cam_lock)

    @property
    def z_ceiling(self) -> float:
        return self.ceiling_h

    @property
    def z_body_rim(self) -> float:
        return self.z_ceiling - 0.15

    @property
    def z_groove_lo(self) -> float:
        """Seal sits high, above the channels, centred in the plain band."""
        return (self.z_chan_hi + self.z_body_rim) / 2 - self.groove_w / 2

    # --- Flipped board stack ------------------------------------------------
    @property
    def r_pocket(self) -> float:
        """Pocket the holder nests in, centred on the offset."""
        return self.r_holder + self.fit_holder

    @property
    def z_fill_top(self) -> float:
        """Top of the fill around the cell; clears the PCB face."""
        return self.holder_h - self.fill_relief

    @property
    def z_pcb_bottom(self) -> float:
        return self.holder_h

    @property
    def z_pcb_top(self) -> float:
        return self.holder_h + self.pcb_env_h

    # --- Harness tabs -------------------------------------------------------
    @property
    def r_slot_in(self) -> float:
        return self.r_cap_out + self.tab_inner_wall

    @property
    def r_slot_out(self) -> float:
        return self.r_slot_in + self.strap_t

    @property
    def r_tab_out(self) -> float:
        return self.r_slot_out + self.tab_bar

    # --- Sourcing -----------------------------------------------------------
    def oring_id_target(self) -> float:
        return 2 * (self.r_groove_root - self.oring_cs)

    def actual_squeeze(self) -> float:
        return (self.r_core - (self.r_groove_root - self.oring_cs)) / self.oring_cs


P = Params()


# --- helpers -----------------------------------------------------------------
def cyl(r: float, h: float, z: float = 0.0) -> bd.Solid:
    return bd.Pos(0, 0, z) * bd.Cylinder(
        r, h, align=(bd.Align.CENTER, bd.Align.CENTER, bd.Align.MIN))


def ring(r_out: float, r_in: float, h: float, z: float = 0.0) -> bd.Solid:
    return cyl(r_out, h, z) - cyl(r_in, h, z)


def sector(r_out: float, r_in: float, a0: float, a1: float, h: float,
           z: float = 0.0) -> bd.Solid:
    """Annular sector from angle a0 to a1 (degrees, CCW from +X)."""
    n = max(2, int((a1 - a0) / 5) + 1)
    R = r_out + 2.0
    pts = [(0.0, 0.0)] + [
        (R * math.cos(math.radians(a0 + (a1 - a0) * i / n)),
         R * math.sin(math.radians(a0 + (a1 - a0) * i / n)))
        for i in range(n + 1)]
    wedge = bd.Pos(0, 0, z) * bd.extrude(bd.Polygon(*pts, align=None), amount=h)
    return wedge & ring(r_out, r_in, h, z)


def helical_sector(profile_rz: list[tuple[float, float]], r_ref: float,
                   start: float, span: float, pitch: float,
                   z_start: float) -> bd.Solid:
    """Sweep an (r, z) polygon along a right-handed helix.

    The profile is given in radial/axial coordinates at `start`, z relative to
    z_start; the result covers `span` degrees and rises pitch * span / 360.
    Lugs and lips are both built this way with the same pitch, so at the
    locked position their bearing flats are parallel and touch over their
    full width instead of along one edge.
    """
    path = bd.Helix(pitch=pitch, height=pitch * span / 360.0, radius=r_ref)
    # Profile plane: x radial outward, y axial up. Using the negated path
    # tangent as the plane normal is what makes local y point up.
    plane = bd.Plane(origin=path @ 0, x_dir=(1, 0, 0), z_dir=-(path % 0))
    face = plane * bd.make_face(bd.Polyline(
        *[bd.Vector(r - r_ref, z, 0) for r, z in profile_rz], close=True))
    solid = bd.sweep(face, path=path, is_frenet=True)
    return bd.Pos(0, 0, z_start) * (bd.Rot(0, 0, start) * solid)


# --- closure -----------------------------------------------------------------
def body_lugs(p: Params) -> bd.Solid:
    """Bayonet lugs on the seal band.

    Underside: a cone at chamfer_deg from the cap's bore radius out to the
    crest -- no flat, so nothing for the slicer to support. It lies on the
    same cone as the cap's lip tops and follows the ramp helix, so the two
    mate face to face. The 0.10 mm under the bore radius is flat but sits
    against the band. The top is cut flat afterwards, it carries nothing.
    """
    r_bear = p.r_cap_seal_bore
    rise = p.chamfer_rise(p.r_lug - r_bear)
    over = p.lug_h + p.cam_rate * p.lug_arc + 0.5      # trimmed flat below
    prof = [(p.r_core - 0.30, 0.0), (r_bear, 0.0),
            (p.r_lug, rise), (p.r_lug, over), (p.r_core - 0.30, over)]
    lugs = None
    for i in range(p.lug_n):
        lug = helical_sector(prof, p.r_lug - 0.4,
                             p.lug_angle(i) - p.lug_arc / 2, p.lug_arc,
                             p.cam_pitch, p.lug_z - p.cam_rate * p.lug_arc / 2)
        lugs = lug if lugs is None else lugs + lug
    return lugs - cyl(p.r_lug + 1, 5, z=p.lug_z + p.lug_h)


def cap_channels(p: Params) -> tuple[bd.Solid, bd.Solid]:
    """The cap's L-channels: (material to cut, lips to add back).

    Built in the cap's LOCKED orientation, so the cap solid is already in its
    assembled pose. For lug i at angle a: the entry slot is centred at
    a - cam_lock (the cap turns clockwise to lock), full height from the
    skirt's open end to z_chan_hi; the circumferential leg runs from the slot
    to the end wall at a - cam_lock + chan_end. Under the leg sits the lip, a
    helical ramp rising cam_rate per degree, parallel to the lug undersides.
    Its top is a cone at chamfer_deg from the bore up to the channel root,
    the lug undersides' cone -- once the cap is flipped for printing it
    overhangs at 50 deg and needs no support.
    """
    r_in = p.r_cap_seal_bore
    r_out = p.r_cap_chan + 0.05          # embeds into the wall: no coincident face
    rise = p.chamfer_rise(r_out - r_in)
    prof = [(r_in, -1.0), (r_out, -1.0), (r_out, rise), (r_in, 0.0)]
    cut = lips = None
    for i in range(p.lug_n):
        e = p.lug_angle(i) - p.cam_lock
        c = sector(p.r_cap_chan, r_in - 0.8, e - p.entry_half, e + p.chan_end,
                   p.z_chan_hi - p.z_shoulder + 0.5, p.z_shoulder - 0.5)
        lip = helical_sector(prof, p.r_cap_chan - 0.4, e + p.entry_half,
                             p.chan_end - p.entry_half, p.cam_pitch, p.z_lip_lo)
        cut = c if cut is None else cut + c
        lips = lip if lips is None else lips + lip
    return cut, lips


def cell_fill(p: Params) -> bd.Solid:
    """Fill around the cell, so the enclosure itself holds the holder.

    With the board flipped the holder sits on the floor, and the crescent of
    cavity it does not occupy gets filled to just under the PCB face. That fill
    is what stops the holder shifting. At the tangent point the cavity wall
    already backs the cell, so nothing extra is needed there.

    The fill deliberately stops short of the PCB (fill_relief): the board still
    rests on its own holder, and the foam ring in the cap still absorbs the
    unresolved stack tolerance. Seating the PCB on the fill instead would put
    the fill in contact with whatever components sit on that face, which is
    not known.
    """
    pocket = bd.Pos(p.holder_offset, 0, 0) * bd.Cylinder(
        p.r_pocket, p.z_fill_top + 1,
        align=(bd.Align.CENTER, bd.Align.CENTER, bd.Align.MIN))
    return cyl(p.r_cav, p.z_fill_top, z=0.0) - pocket


def strap_tabs(p: Params) -> bd.Solid:
    """Two flat side tabs in the plane of the base, each a slot plus a bar.

    Replaces the earlier under-floor bridges. The tag's underside is now
    completely flat and the elastic wraps the bar at each tip, lying level with
    the base instead of running beneath the tag.

    The root is only as tall as the base flange, because above z_shoulder and
    inside r_cap_out the space belongs to the cap skirt. Outboard of the cap the
    tab is full thickness. The root carries harness load in tension rather than
    bending, so the thin section is not the weak point it appears to be.
    """
    tabs = None
    for sign in (+1, -1):
        root = bd.Pos(sign * (p.r_cav + p.r_cap_out) / 2, 0, -p.floor_t) * bd.Box(
            p.r_cap_out - p.r_cav, p.tab_w, p.floor_t + p.z_shoulder,
            align=(bd.Align.CENTER, bd.Align.CENTER, bd.Align.MIN))
        outer = bd.Pos(sign * (p.r_cap_out + p.r_tab_out) / 2, 0,
                       -p.floor_t) * bd.Box(
            p.r_tab_out - p.r_cap_out, p.tab_w, p.floor_t + p.tab_top,
            align=(bd.Align.CENTER, bd.Align.CENTER, bd.Align.MIN))
        # Trim the outer edge to an arc about the tag centre. The tab is wider
        # than it is long, so a semicircular tip would overhang; this rounds it
        # without adding reach.
        outer &= cyl(p.r_tab_out, p.floor_t + p.tab_top + 2, z=-p.floor_t - 1)

        slot = bd.Pos(sign * (p.r_slot_in + p.r_slot_out) / 2, 0,
                      -p.floor_t - 1) * bd.Box(
            p.strap_t, p.strap_w, p.floor_t + p.tab_top + 2,
            align=(bd.Align.CENTER, bd.Align.CENTER, bd.Align.MIN))

        tab = (root + outer) - slot
        tabs = tab if tabs is None else tabs + tab
    return tabs


# --- parts -------------------------------------------------------------------
def build_body(p: Params = P) -> bd.Solid:
    """Cup: floor, cavity, bayonet lugs low, sealing band high, cell fill, tabs."""
    body = cyl(p.r_cap_out, p.floor_t + p.z_shoulder, z=-p.floor_t)
    body += cyl(p.r_core, p.z_body_rim - p.z_shoulder, z=p.z_shoulder)
    body += body_lugs(p)
    body -= cyl(p.r_cav, p.z_body_rim + 1, z=0)

    # Lead-in chamfer so the O-ring rolls onto the band instead of shearing.
    # The cone must taper INWARD going up. Widening it upward instead cuts the
    # wall to a 0.10 mm edge low down and leaves a downward-facing annular
    # shelf above it -- an undercut the slicer reports as a floating
    # cantilever, and a knife edge that cannot print.
    ch = 0.4
    body -= bd.Pos(0, 0, p.z_body_rim - ch) * (
        bd.Cylinder(p.r_core + 1, ch,
                    align=(bd.Align.CENTER, bd.Align.CENTER, bd.Align.MIN))
        - bd.Cone(p.r_core + 1.0, p.r_core - ch, ch,
                  align=(bd.Align.CENTER, bd.Align.CENTER, bd.Align.MIN)))

    return body + cell_fill(p) + strap_tabs(p)
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

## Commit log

2026-09-01 v1: parametric hen-tag enclosure, cap generator, verification suite
    Extracted as a standalone public repository from the Remeny Farm hen-tag
    project. Contains the Revision B parametric enclosure (build123d), the
    deterministic per-hen cap generator, 29-check machine verification, the
    test suite, dated physical lab notes, and the accessory-platform proposal.
    [body.step, body.stl, body_platform.step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]
2026-09-10 Revision C: bayonet closure replaces the thread; slicer toolpath check
    The Tr28.6 x 1.0 thread tore in print: its cap ridge crest computes to
    0.05 mm and its flanks are 75 deg overhangs. Replace it with a three-lug
    bayonet - lugs on the body's seal band, L-channels in the cap, helical
    lips at 12 um/deg (self-locking) that wedge the skirt onto the base
    flange after 30 deg clockwise. On both parts, in print orientation, the
    only flat overhang is the 0.5 mm bearing flat. Seal, cap OD, scallops,
    tabs, lettering, LED ring and the platform interface are unchanged.
    verify.py: 38 checks (drop-on, free run, wedge, retention, lift-off,
    self-locking, print-error window). Thread code and bd_warehouse r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
    [body.step, body.stl, body_platform.step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]
2026-09-14 docs: design spec for patron hen-cap customisation
    Patrons choose a colour scheme, an icon or centre pattern and a top-band
    pattern for their hen's cap, preview it live and lock it; staff batch one
    scheme per plate (6 x 6), generate the print file on the farm Mac from a
    batch JSON, print and install. Covers the physical constraints, the
    catalog, the batch contract, the generator and batch-CLI changes in this
    repository, a drop-in patron editor prototype built with chirp's UI
    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
2026-09-14 feat(cad): catalog manifest, design hash, parity test
2026-09-14 feat(cad): centre and band patterns, egg/sun/moon icons, printability checks
2026-09-14 feat(cad): layout JSON for the app preview and proof SVG export
2026-09-14 feat(cad): pure-Python Bambu plate writer
2026-09-14 feat(cad): batch CLI: batch JSON to plate, manifest and proofs
2026-09-14 fix(cad): plate is a Bambu Studio project; keep a single filament colour
    Marked as an "other vendor" 3MF the CLI ignored the project settings, used
    a 200 x 200 plate and silently dropped 10 of 36 caps. With the Application
    metadata set, three filament_colour entries make the G-code export fail
    (bisected against every other edit), so the template's single entry stays.
2026-09-14 fix(cad): leave Bambu's per-filament arrays untouched in the plate template
2026-09-14 docs: cap customisation workflow, batch plate lab note
2026-09-14 feat(editor): glyph previews on the centre and band picker tiles; inline the sample proof
2026-09-14 chore: track the editor's pnpm workspace file; ignore batch logs
2026-09-14 feat: Prusament palettes with a base colour and clear LED window
    Three tiers from the Prusament PETG range: Pasture (Pistachio Green /
    Jet Black / Signal White, free), Blue-dye (Ocean Blue / Signal White /
    Chalky Blue, 100), Gold (Galaxy Black / Yellow Gold / Signal White, 500).
    Red and bright colours are avoided: the flock has active feather pecking.
    The catalog carries the base filament; the layout exports the LED window
    (r 8.5-11.5) and the preview draws the base-coloured shell with the clear
    ring the number overlaps. Hash vectors and fixtures follow the new ids.
    The four-body generator (base shell + clear window) is not built yet.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
    [cap_marking.py, cap_svg.py]
2026-09-14 feat: free zone colours, motif packs, number above the LED window
    Each cap is now four bodies for four AMS slots: base-coloured shell, clear
    LED window (r 8.5-11.5 through the top plate), and the scheme's two free
    colours a/b assigned per zone (outer ring, number, inner disc, centre
    element, band pattern) with the catalog rules number != ring, centre !=
    disc, band != ring. The number shrinks to 4.5 pt so it never enters the
    window; the staff message to 3.6 pt.
    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
2026-09-14 feat: clear is the fourth colour; any zone may take it, the LED annulus always does
    The clear body starts as the mandatory window annulus and grows by every
    zone or inlay assigned to clear. The readability rule stays number != ring,
    so a clear number needs an opaque ring and vice versa. The preview renders
    clear as frosted glass tinted by the base colour; the colour rows show a
    fourth, glass chip.
2026-09-14 feat(editor): game-like three-step cap editor with the cap on stage
    Palette > Motif > Colours as a numbered segmented tablist, the cap on a
    lit stage that settles on every change and shines with gold sparks on a
    lock, pack rails (Basic / Vibe / Drop, limited) that scroll sideways
    instead of a 26-icon wall, the chosen motif's colour chips right above its
    rail with the blocked chip crossed and explained, a sticky summary bar
    (total, wallet, Next / Lock) above the home indicator, a bottom-sheet lock
    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
2026-09-14 fix(editor): rails scroll instead of the page; contrast; layout gate
    Two causes stretched the document sideways on the Motif step: grid tracks
    growing to their content (now minmax(0, 1fr) and min-inline-size: 0 down the
    chain, contain: inline-size on the rail group, overflow-x only on the rail)
    and the visually hidden radios, whose containing block was the page (tiles
    and cards are now position: relative). Keyboard focus in a rail aligns the
    tile to its snap start so the proximity snap cannot pull it back out of
    view. Scheme-card blurb and the summary-bar label use ink instead of muted
    (7.3:1 and 12.5:1). New pnpm check:layout drives Chromium against the dev
    server and fails on page-level ho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
2026-09-14 feat(editor): paging arrows and edge fades on the motif and band rails
2026-09-19 feat(catalog): 2026-09-18 palettes, eight new icons, a translucent rule (#1)
    Brings the generator level with the catalog the chirp app ships.
    catalog.json is now the chirp copy byte for byte except generator_version,
    which moves from "dev" to "2026-09-18" (chirp mirrors the same string; the
    batch CLI refuses any other value, and layout.json carries it).
    - Schemes: eggshell (free), lavender, mocha, pinewood (100) on Bambu Lab
    PETG Basic, lavender's colour b Bambu PETG Translucent Purple; emerald_gold
    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
2026-09-24 Revision D: board from the manufacturer STEP; support-free bayonet and groove
    Board geometry now comes from Holyiot's STEP (HOLYIOT-25008-V1.0.step) via
    cad/board_holyiot_25008.py: a 0.81 mm board with parts up to 1.60 mm (the
    centre switch S1), LED at r 9.84 / -60 deg. The caliper's 2.0 mm "board"
    left the rim foam ring hanging 1.1 mm above the board and sitting on the
    LED; the foam is now an inboard OD16 x ID12 x 2.0 ring. The ceiling stays
    at z 6.60, 0.19 mm over S1. The STEP's battery clip is a generic model and
    is ignored. `verify.py --board-step PATH` re-extracts the numbers and
    collides the real board with body and cap.
    The cap's bayonet lips and the O-ring groove's lower flank had f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
    [body.step, body.stl, cap.step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]
2026-09-24 fix(batch): cache plain faces so the body cache pickles under build123d 0.13 (#3)
    build123d 0.13 (OCCT 8.0) keeps a BRepTools_History on boolean results,
    and pickling the 2D sketches for the body cache failed with "cannot pickle
    BRepTools_History" -- every batch run died before writing a plate. The
    cache now stores the sketches' faces as a plain Compound, which is all
    cap_svg's proof writer reads. The generator fingerprint also covers
    board_holyiot_25008.py, which hen_tag_enclosure imports since revision D.
    test_cap_batch.py: 16/16 (was 10/16).
    [cap_batch.py]
2026-09-25 feat(platform): full keeper collar v1, support-free, plus demo halo accessory (#4)
    Adds cad/collar_full.py, which builds both clamshell halves and a halo
    accessory on the bayonet, and cad/overhang.py, a mesh check for downward
    faces steeper than 45 deg above the bed. v1 replaces the floating pegs,
    shoulder pads and accessory lugs of the rejected v0 with bed-standing
    features. Interference is 0.000 mm3 against body_platform, the cap, the
    other half and the halo. It also regenerates the platform coupons against the
    Revision D body.
    [body_platform.step, body_platform.stl, collar_half_a.step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]
